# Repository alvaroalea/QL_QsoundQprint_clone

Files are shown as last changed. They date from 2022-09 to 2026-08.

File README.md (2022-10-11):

# SINCLAIR QL QsoundQprint Sound and Paralel Printer port interface

(C) 2022 Alvaro Alea Fernandez

License under: CERN Open Hardware Licence Version 2 - Strongly Reciprocal

https://ohwr.org/cern_ohl_s_v2.txt

I try to follow the original desing as much as possible, with some licenses:

- It's 10mm short, to fit in a 10x10cm, that is a lot cheaps if order PCB.
- The 7805 regulator board and the output Jack was modify.
- I use a electrolitic capacitor instead the original tantalo one.
- There are some jumper to allow a future ACB stereo mix.

This project can not be possible without the help of silvester, that tracked a fault in the schematic and Marcel Kilgus that develop a new ROM with a qsound device and a pt3 player.

I test with ROM versions 1.10, 1.31 and 1.40 and work as expected, new ROM do not have the printer routines, but have a new options used by the pt3 player. 

You can use a 2764 eprom or a W27C512 flash, that is much more cheap and easy to use.

This board user the default Motorola 68K inteface as described in the documentation of AY-3-8910 PSG. with a 6821 PIA as a glue between the QL and the PSG, in the info folder you can found aditional information about this chips or the interface.

The card have full 8bit I/O in the PSG without use, and another 8 bits in the PIA, also the pins of the paralel port are directly wired to the PSG, and are bidirectional, so can be used for other propouses.

The board use the E signal as a clock for the PSG, this cause that the PSG work in a very low frecuency, below the minimun indicated in the datasheet, and also this cause that tunes from Spectrum or other systems, can not be directly converted.

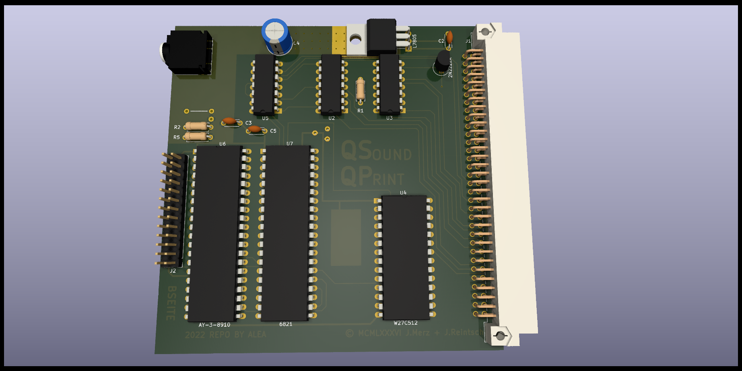
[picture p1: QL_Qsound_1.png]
 

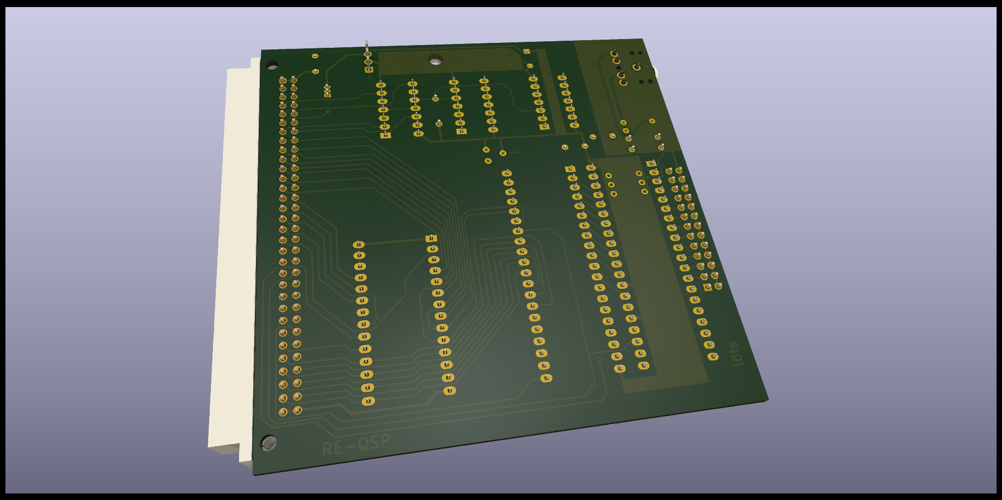
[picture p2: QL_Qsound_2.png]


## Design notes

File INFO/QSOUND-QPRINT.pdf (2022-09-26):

QSOUND/QPRIIdT - MANUAL | PAGE 1
This upgrade adds to the good characteristics | of the QL a 'real' sound generation facility and a parallel | printer

interface.
he boy
Ensure that the ",r is dis | . If you do

not you may damagr the QL, the QSOUND/QPRINT board or both. Remove the rectangular plastic cover on the left hand side of your QL which covers the expansion bus slot. This may require some effort.

Now push the QSOUNDIQPRINT board | firmly in the expansion
slot. | This may take also a little effort. You should be able
to feel when the board is firmly in place.

To test your new upgrade connect the QL to the mains. After
the usual memory test screen, the TV/Monitor selection screen will | appear with a11 additional copyright message | from the

QSOUND/QPRINT board. If you have connected an amplifier you should hear a short sound like a bell: QSOUND/QPRINT tells you that it is OK! After pressing F1 (or F2) you can use the full power of your QSOUND/QPRINT expansion.
To connect an amplifier to the QSOUND/QPRINT card, there is a 3.5 mm cinch socket on the left hand side of the card. | You
will also find a centronics compatible printer | interface
there,

Obligatory notice
QL, QDOS. Microdrive and SuoerBASIC are trade marks of ~inciair Research Ltd.
ABACUS, ARCHIVE, EASEL and QUILL are trade marks of Psion Ltd.

QSOUND/QPRINT - MANUAL | PAGE 2

lr_se
After powering up and initialisation | you can use a | new QL
device named PAR.
You can connect a Centronics | compatible printer | to | the
parallel interface and use it via the device name PAR.
A procedure to | list | the actual | SuperBASIC | program | to a
printer connected to the PAR port could look like this:

30000 DEFine PROCedure llist
30001 OPEN #3,PAR : LIST #3 : CLOSE #3 30002 END DEFine

### Bwffers

You can use a part of the QL's RAM as a buffer for efficient
print spooling. Its size In | blocks | of | 512 bytes must be
specified in the OPEN command as in the following examples:

OPEN #3, PAR-1
OPEN $3, PAR-32

512 byte buffer
16 kbyte buffer
The maximum buffer size is 63 kbytes.

Oations
Two options are accepted as part of the device name.
PARC-(bfsize) | The | 'C' flag | is used | if the | <LF> character
(chrS(10)) should be converted | to a | (CR>
character (chrS(13)).
PARF-<bfsize> | The 'F' flag is used | if a | IFF) | character
should be sent when the channel is closed. PARCF-(bfsize) Combination of the two flags is allowed.

SER em-Using the new PAR-USE command you can get the benefits of
your | new | parallel | interface | without changing existing
hrograms. | his command accepts a three character device name
!wrth or without string quotes) as a parameter.
PAR-USE SER | will | emulate the | SEX ports of the QL. All
output sent to the serial port will be send to the new PAR device.

Psion software
If you want | to use | the PAR | interface with ABACUS, ARCHIVE
EASEL and QUILL you may | include the PAR-USE - | command in the
corresponding boot prog;am.
Alternativly, you can also change the printer driver with the

QSOUND/QPRINT - MANUAL | PAGE 3

INSTALL-BAS program supplied with the Psion software package: Lead and run the program and choose the Microdrive as required. Choose the PAR port option by pressing the space bar. Get the list of printer parameters by pressing F2. Change the PORT by pressing either the left or right cursor key and then type 'PARf as the valid device name. Donft use a buffer unless you have a memory expansion as the

Psion programs use the entire RAM of an unexpanded QL.
Don't add the flags 'C' or 'Ft, You can obtain these options specifying the END OF LINE code as CR and by including FF in the POSTAMBLE CODE, respectively.

QSOUND/QPRINT - MANUAL | PAGE 4

The QSOUND/QPRINT firmware consists of 30 new SuperBASIC commands which allow you to utilize the PAR interface and the
full capability of | the | sound | chip. | A | few | useful
procedures/functions are also included.
The commands are described below. Parameters enclosed in < > are optional. The default window is #l.
BELL

CONTROL

CUR-FLASH f

CURDIS <#n>

CURSEN <#n>

procedure
causes the sound chip to emit a short bell like sound
procedure
creates a job which opens a window in the upper right-hand corner of the screen shows the number of the job that is currently ready to receive input (i.e. whose cursor is flashing)
procedure
changes the flashing rate of the cursor f = 0 | normal
f = 1 | medium
f = 2 | high

procedure
disables the cursor in window #n

procedure
enables the cursor in window #n
The INKEYS | command doesn't | show | a cursor. | The following | function also
returns the character corresponding to the key pressed but shpws a flashing cursor for the number of frames specified in m:

DEFine FUNction getkeyS(chn, wait) CURSEN #chn
rS=INKEYS(#chn, wait)
CURDIS #chn
RETurn rS
END DEFine
function
returns the current display mode m = 4 high resolution (4 c~lours) m = 8 low resolution (8 colours)

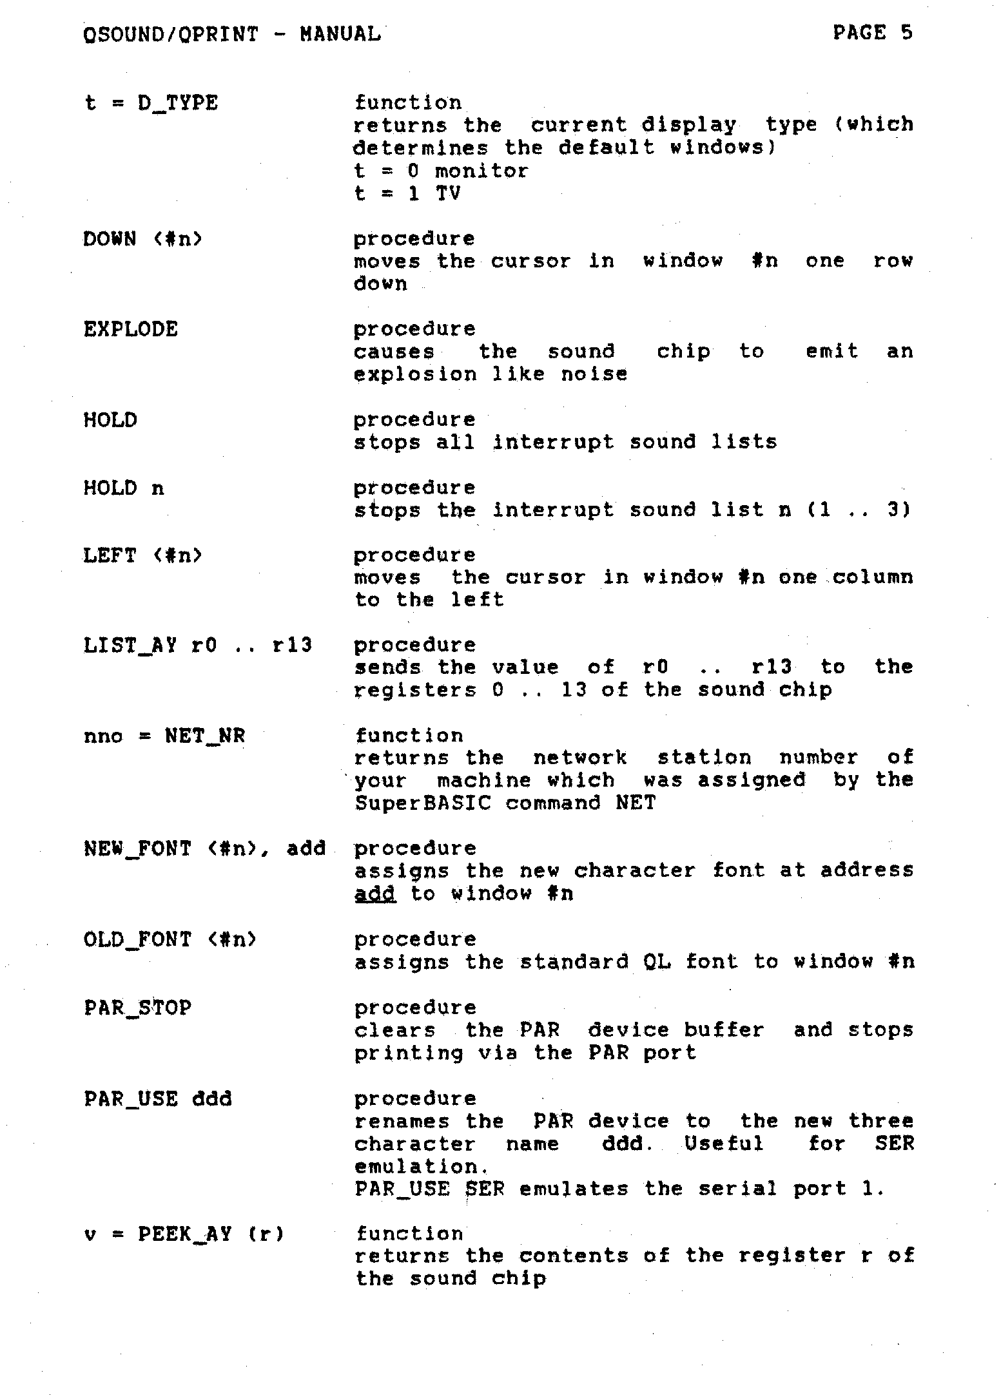
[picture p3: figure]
OSOUNDIQPRINT - MANUAL; PACE 5; DOWN <#n>; EXPLODE; HOLD; HOLD n; LEFT <In>; LIST-AY rO . .; nno = NET-NR; function returns the current display type (which determines the default windows) t = 0 monitor t=lTV; procedure; procedure stops all interrupt sound lists; to the left; sends the value of rO .. r13 to the registers 0 .. 13 of the sound chip; function returns the network station number of your machine which was assigned by the SuperBASIC command NET; NEW-FONT <#n>. add procedure; to window tn; OLD-FONT <#n>; PAR-STOP; clears the PAR device buffer and stops printing via the PAR port; PAR-USE ddd; renames the PRR device to the new three; character; name; ddd.; Useful; for SER; emulation. PAR-USE 6ER emulates the serial port 1.; v = PEEK-AY Ir ); function; the sound chip

moves the cursor in window Xn one row down

causes | the sound | chip to | emit an explosion like noise

ptocedur e stops the interrupt sound list n (1 .. 3)

moves the cursor in window In one column

assigns the new character font at address

assigns the standard QL font to window tn

returns the contents of the register r of

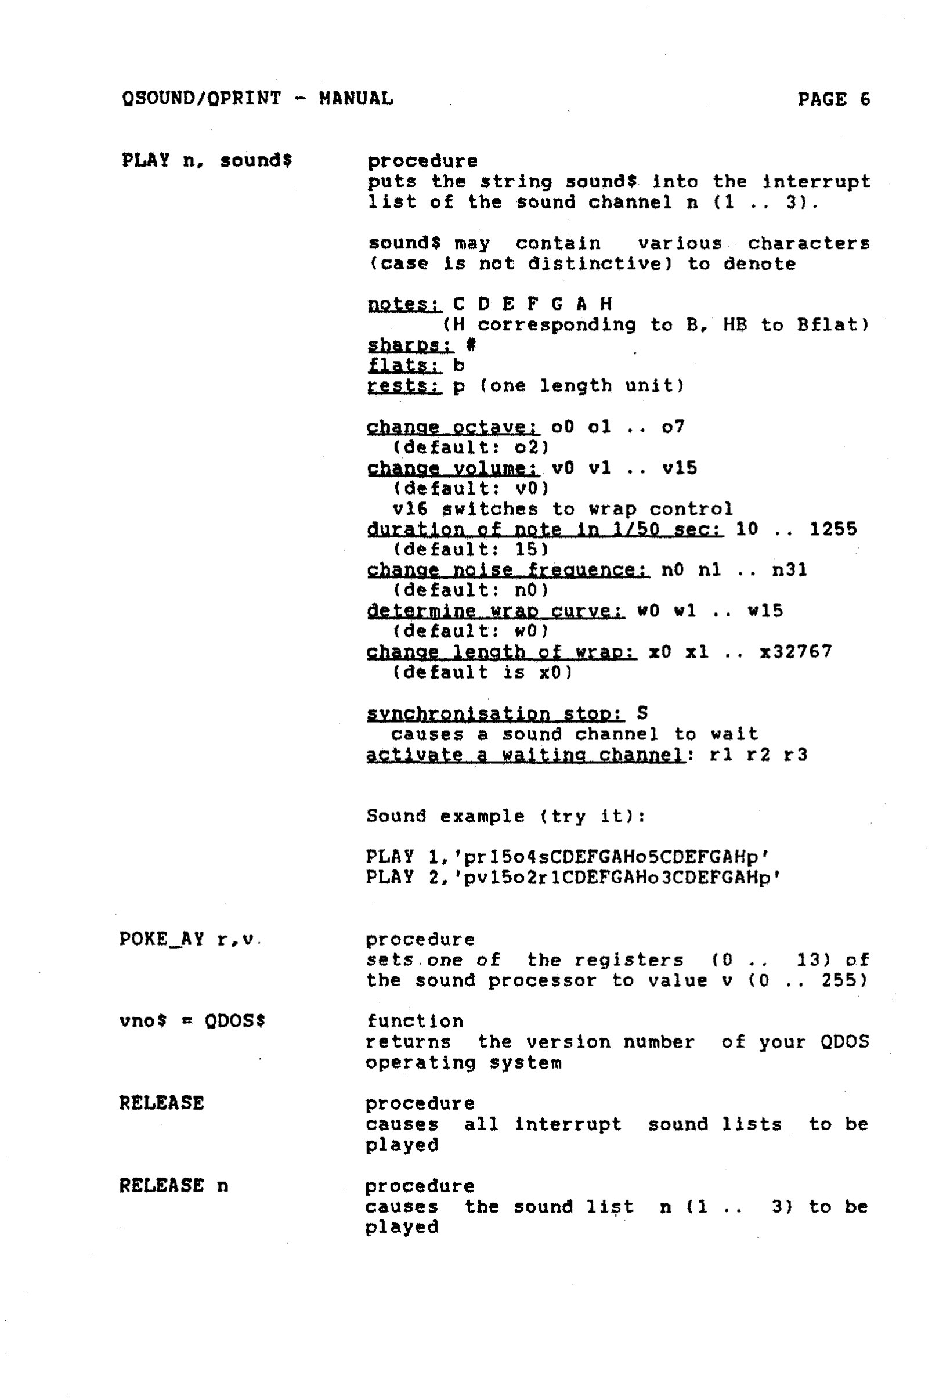
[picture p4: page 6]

QSOUND/QPRINT - MANUAL | PAGE 6
PLAY n, sound$ | procedure
puts the string sound$ into the interrupt list of the sound channel n (1 .. 3).

sound$ may contain various characters (case is not distinctive) to denote wtestC D E F G A H
(H corresponding to B, HB to Bflat) sharas:t
flars:b
rests: p (one length unit)
aanae octave: 00 01 .. 07

(default: 021

chansc v0 vl . . v15

(default: vO)
v16 switches to wrap control
of no* in 1150 sec: 10 ., 1255 (default: 15) * noise freouence: no nl . . n31

(default: no)
wraci curve& uO wl .. w15
(default: wO) oe lenath of wrao: x0 xl .. x32767

(default is xO)

sation stov: S causes a sound channel to wait

activate a waitina chaw: rl r2 r3

SounB example (try it):

PLAY l,'pr1504sCDEFGAHo5CDEFGAHpr PLAY 2,'pv1502r1CDEFGAH03CDEFGAHp'

POKE-AY r,v.

vnoS QDOSS

RELEASE

RELEASE n

procedure
sets one of the registers 10 .. 13) of the sound processor to value v (0 . . 255)

function
returns the version number of your QDOS operating system

procedure
causes all interrupt sound lists to be played

procedure
causes the sound list n (1 .. 3) to be played

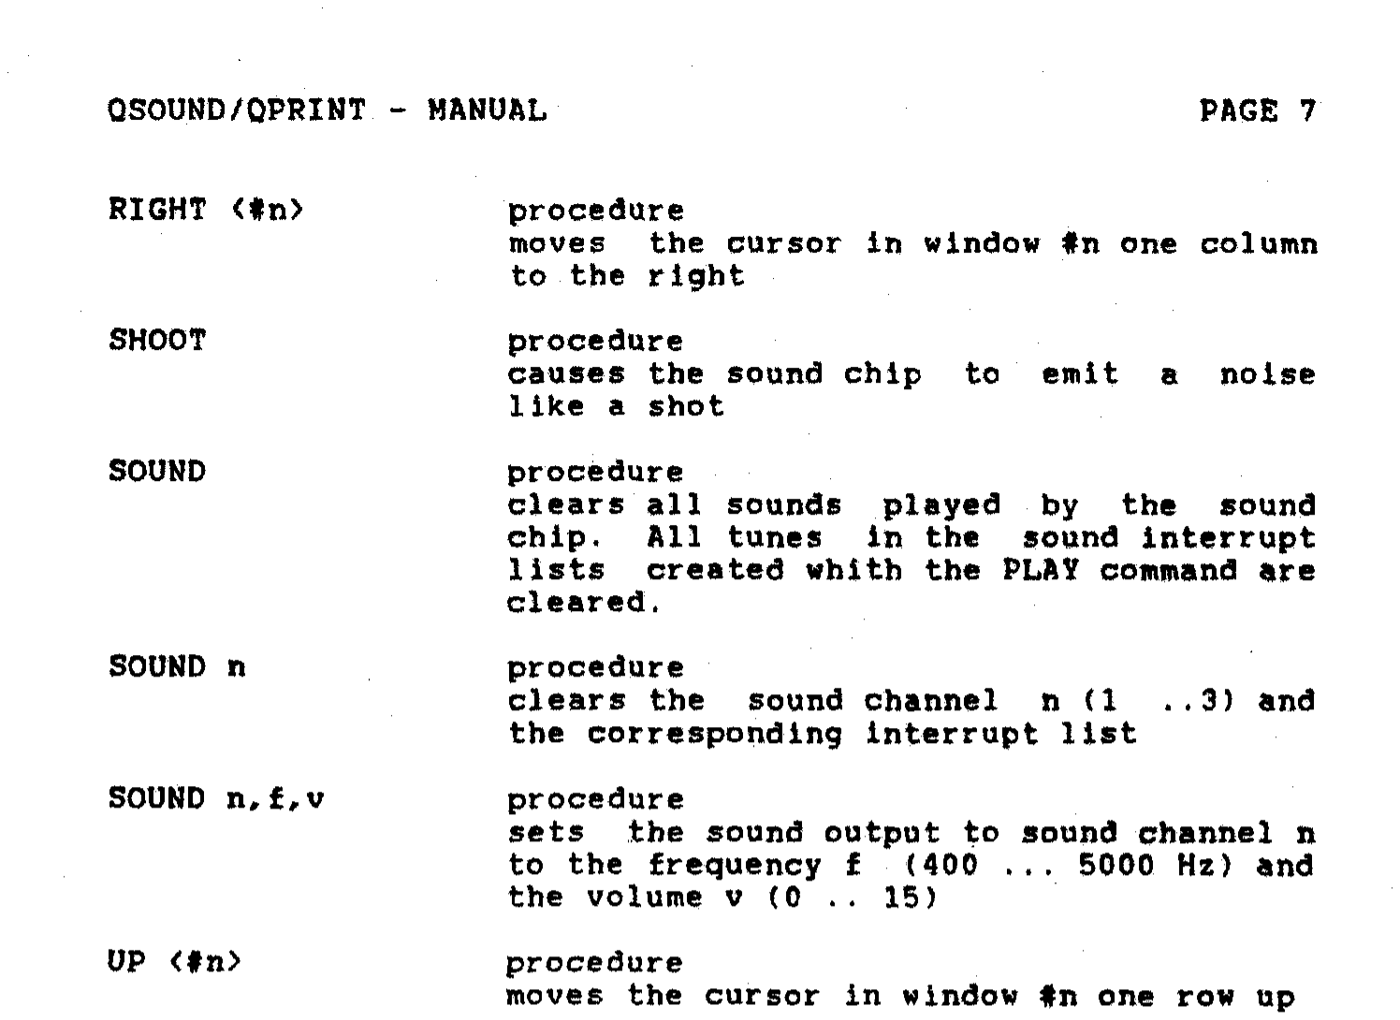
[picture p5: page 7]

QSOUND/QPRINT - MANUAL | PAGE 7
RIGHT <en> | procedure
moves the cursor in window In one column to the right
SHOOT

SOUND

SOUND n

SOUND n, f,v

procedure
causes the sound chip to emit a noise like a shot
procedure
clears all sounds played by the sound ship. All tunes in the sound interrupt lists created whith the PLAY command are cleared.

procedure
clears the sound channel n (1 ..3) and the corresponding interrupt list procedure
sets the sound output to sound channel n to the frequency f (400 ... 5000 Hz) and the volume v (0 .. 15)

procedure
moves the cursor in window #n one row up

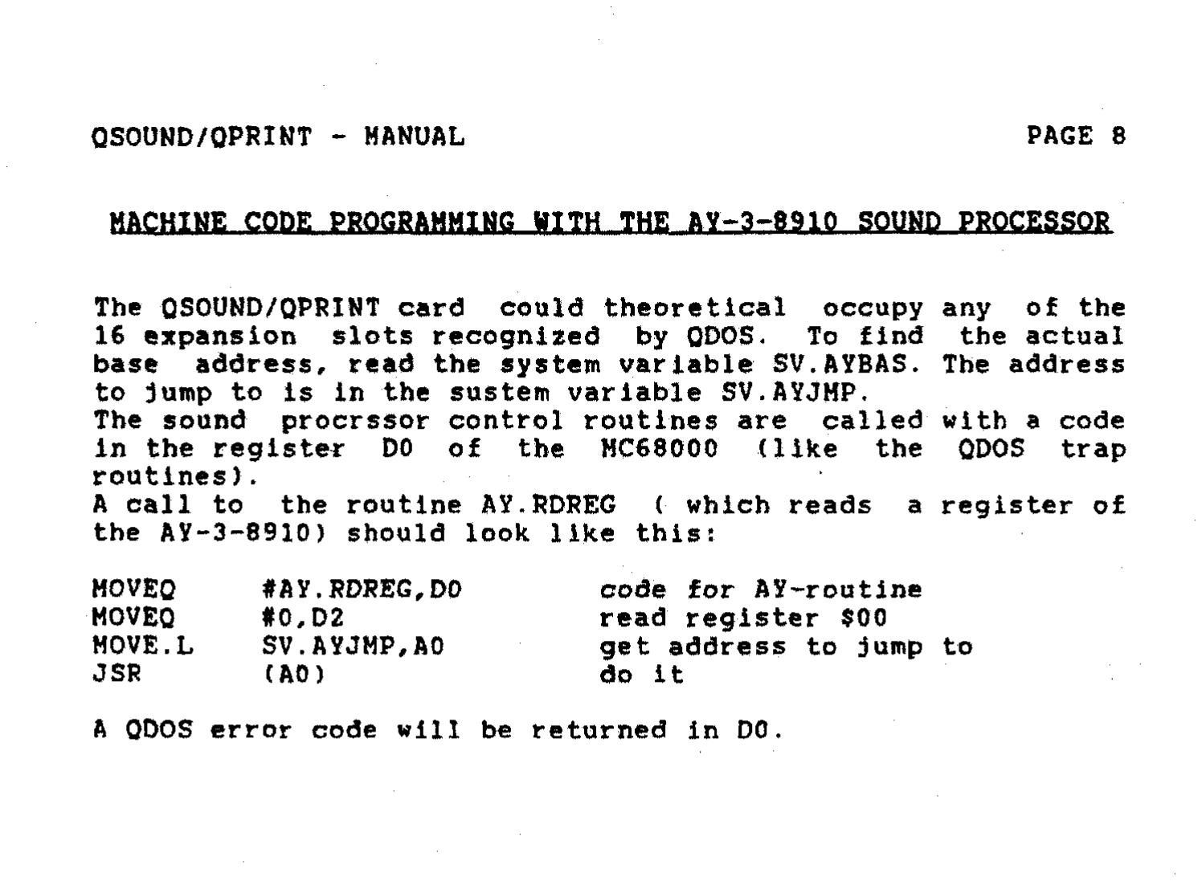
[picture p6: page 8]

QSOUNDlOPRINT - MANUAL | PAGE 8

SOUND PROC=

The QSOUND/QPRINT card could theoretical occupy any of the

### 16 expansion slots recognized by 0005. To find the actual

base address, read the system variable SV.AYBAS. The address to jump to is in the sustem variable SV.AYJNP.
The sound procrssor control routines are called with a code In the register DO of the MC68000 (like the ODOS trap routinesl.
A call to the routine AY.RDREG ( which reads a register of the AY-3-8910) should look like this:
HOVEQ | #AY. RDREG, DO | code for AY-routine
HOVE0 | 20, D2 | read register SO0
H0VE.L | SV.AYJMP,AO | get address to jump to
J SR | (AD) | do it

A QDOS error code will be returned in DO

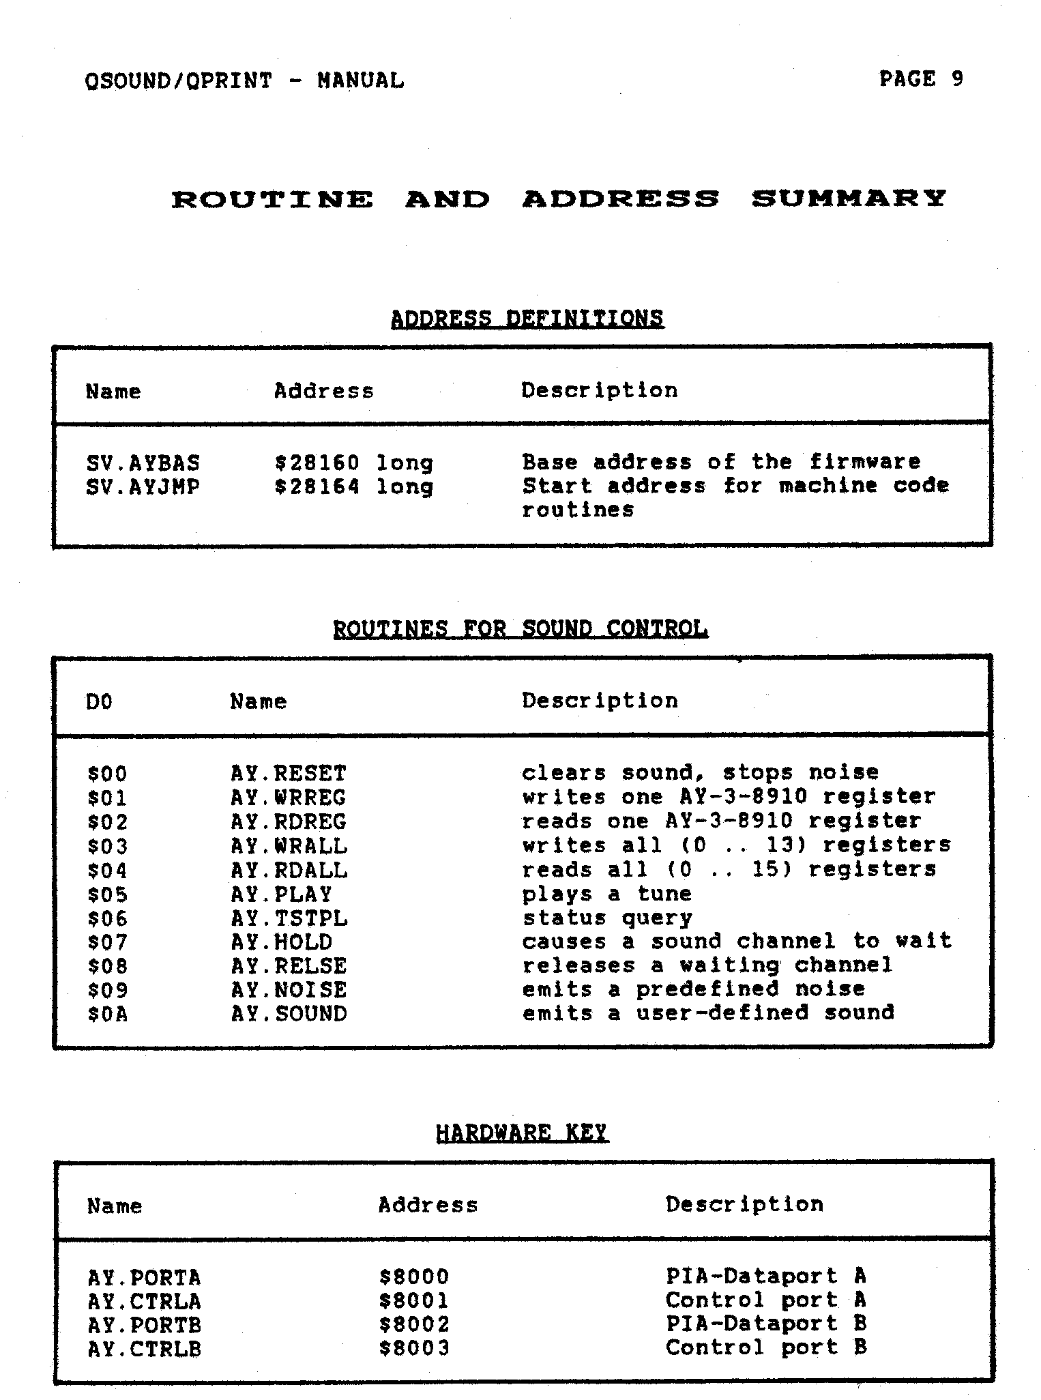
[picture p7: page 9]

QSOUND/PPRINT - MANUAL | PACE 9

ROUTINE AND ADDRESS SUMMARY

Name | Address | Description
SV. AYBAS | $28160 long | Base address of the firmware
SV.AYJMP | $28164 long | Start address for machine code
| | routines
FOR SOUND C | m
I
Name | Description

AY. RESET
AY. WRREG
AY . RDREG
AY. WRALL
AY. RDALL
AY. PLAY
AY. TSTPL
AY .HOLD
AY. RELSE
AY .IOISE
AY. SOUND

clears sound, stops noise
writes one AY-3-8910 register reads one AY-3-8910 register writes all (0 .. 13) registers reads a11 (0 .. 15) registers plays a tune
status query
causes a sound channel to walt releases a waiting channel emits a predefined noise
emits a user-defined sound
I Name | Address | Description | I
I AY. PORTA | $8000
AY, CTRLA | $800 1
AY, PORTB | $8002
AY. CTRLB | $8003 | PIA-Dataport A
| | Control port A PIA-Dataport B
| | Control port B

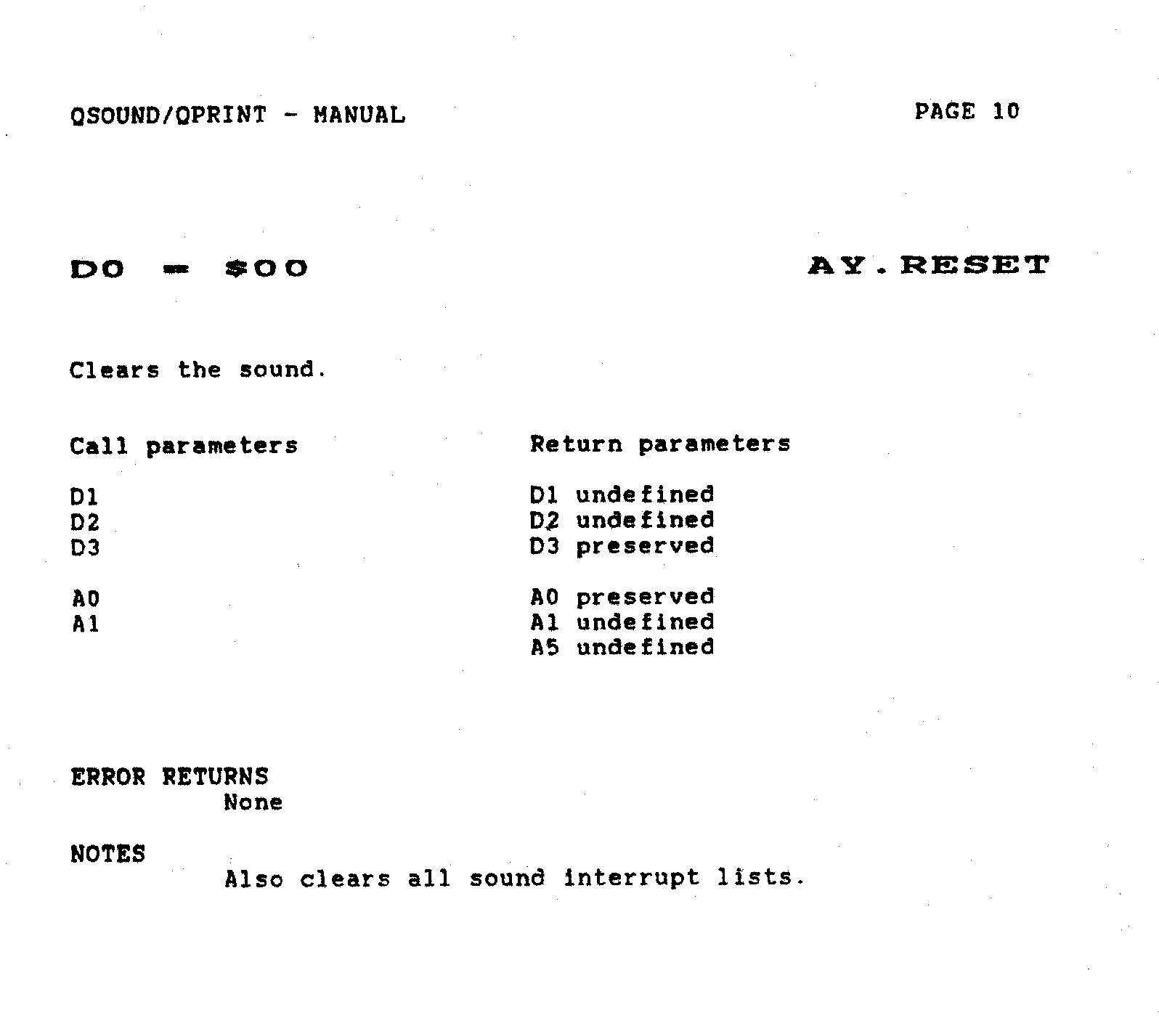
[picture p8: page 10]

QSOUND/QPRINT - MANUAL

Clears the sound.

Call parameters

ERROR RETURNS
None

Return parameters
Dl undefined
D2 undefined

### 03 preserved

A0 preserved
A1 undefined
A5 undefined

PAGE 10

AY, RESET

NOTES
Also clears all sound Interrupt lists.

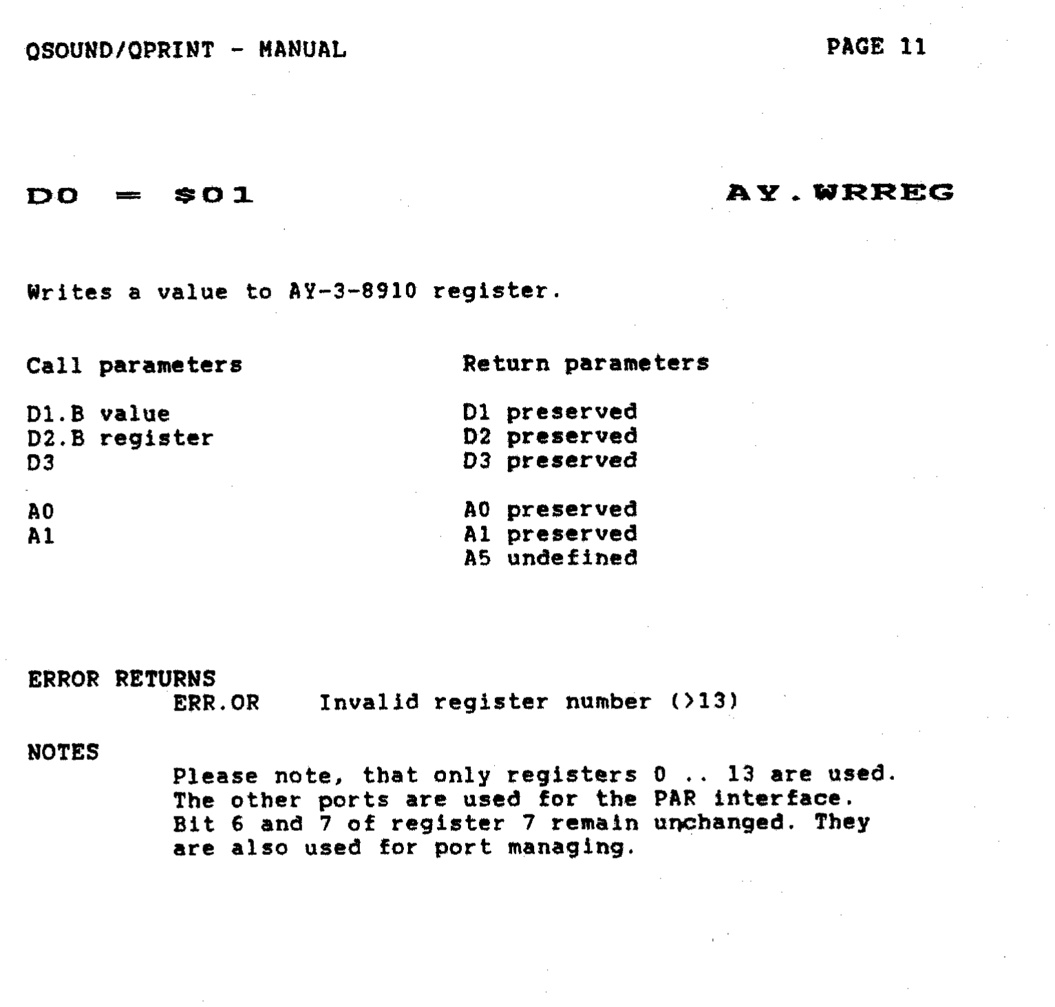
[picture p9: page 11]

QSOUND/PPRINT - MANUAL

Writes a value to AY-3-8910 | register.
Call parameters | Return parameters

AY, WRREG

D1.B value
D2.B register
D 3

Dl preserved
D2 preserved
D3 preserved
A0 preserved
A1 preserved
A5 undefined

PAGE 11

ERROR RETURNS
ERR.OR Invalid register number 013)
NOTES
Please note, that only registers 0 . . 13 are used. The other ports are used Zor the PAR interface. Bit 6 and 7 of register 7 remain unchanged. They are also used for port managing.

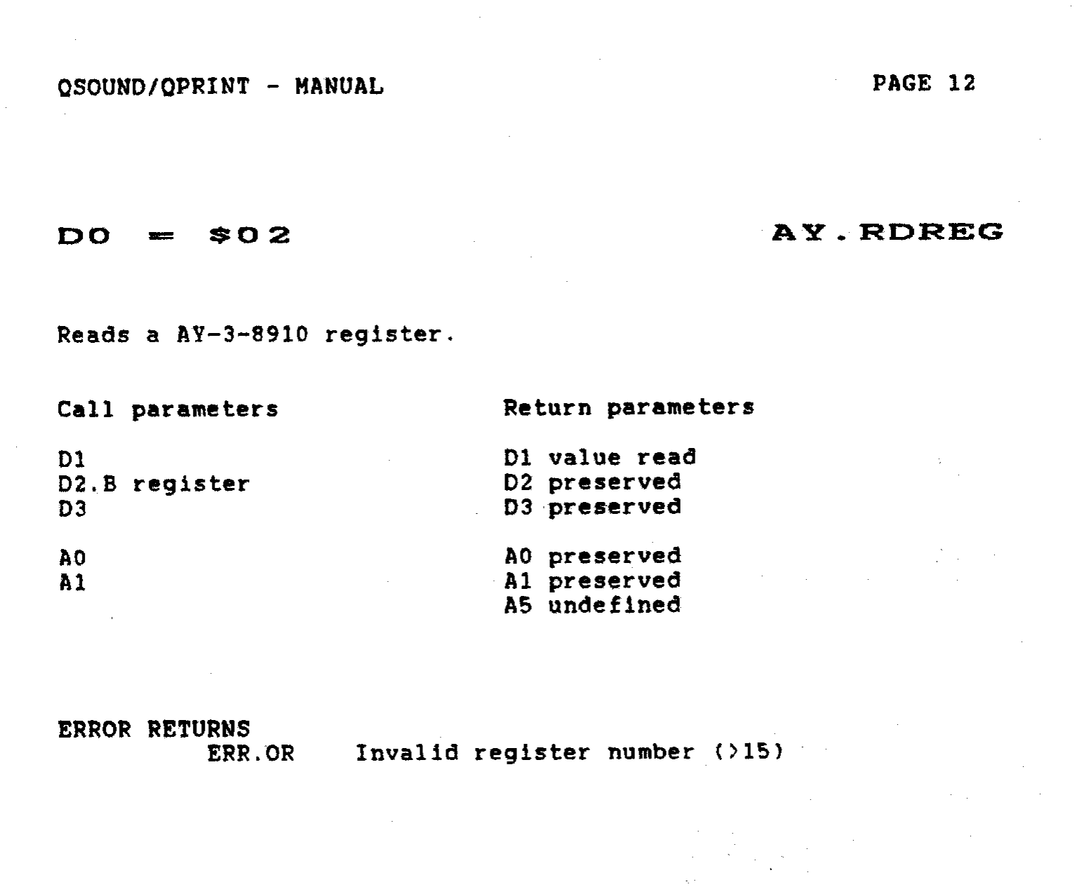
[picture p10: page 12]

QSOUND/QPRINT - MANUAL

Reads a AY-3-8910 register.

Call parameters

D 1
D2.B register
D 3

Return parameters
Dl value read
D2 preserve6
D3 preserved
A0 preserved
A1 preserved
A5 undefined

PAGE 12

AY. RDREG

ERROR RETURNS
ERR.OR Invalid register number 015)

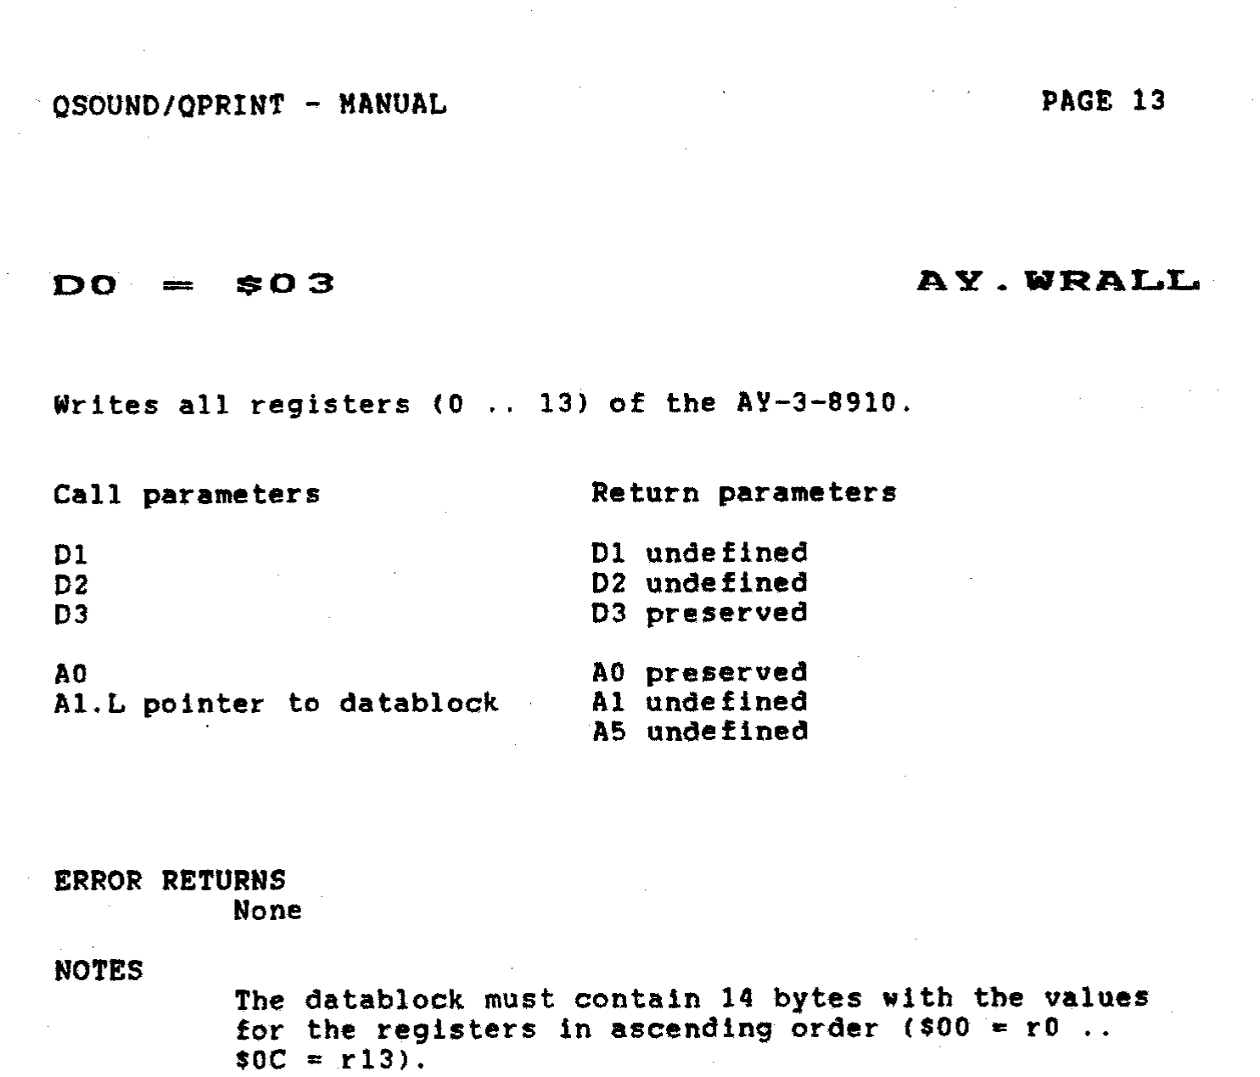
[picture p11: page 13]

QSOUND/QPRINT - MANUAL | PAGE 13
DO | = SO 3 | AY. WRALL

Writes all registers (0 .. 13) of the AY-3-8910.

Call parameters | Return parameters
Dl undef incd
D2 undefined
D3 preserved
A0 | A0 preserved
A1. L pointer to datablock | A1 undefined
A5 undcf ined

ERROR RETURNS
None

NOTES
The datablock must contain 14 bytes with the values for the registers In ascending order ($00 = rO .. SOC = r13).

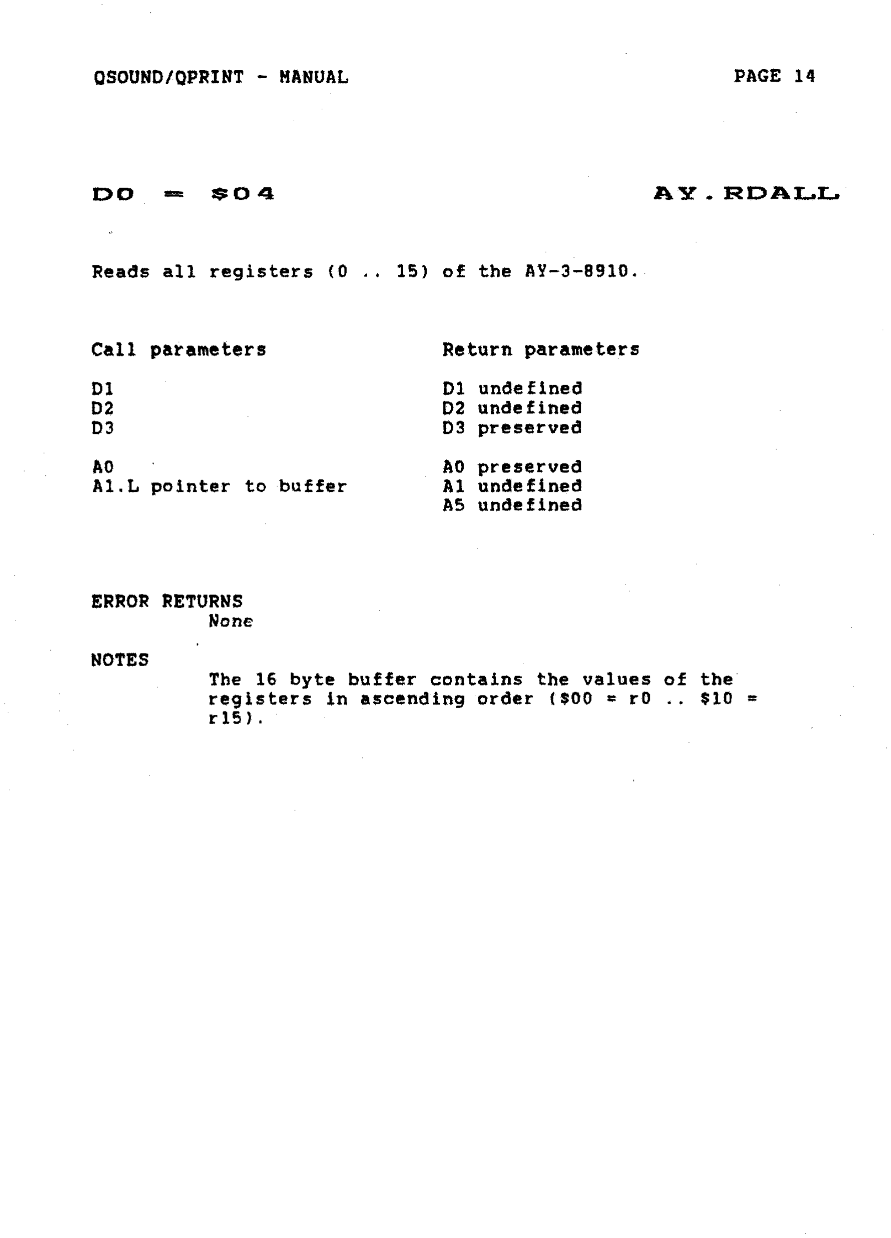
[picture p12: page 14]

OSOUND/QPRINT - MANUAL | PAGE 14

AY, RDALL

Reads all registers (0 .. 15) of the AY-3-8910.

Call parameters | Return parameters
| Dl undefined
| D2 undefined
| D3 preserved
A0 | A0 preserved
A1 .L pointer to buf fcr | A1 undefined
| A5 undefined

ERROR RETURNS
None

NOTES
The 16 byte buffer contains the values of the register; in ascending order 1$00 = rO . . $10 = t-15).

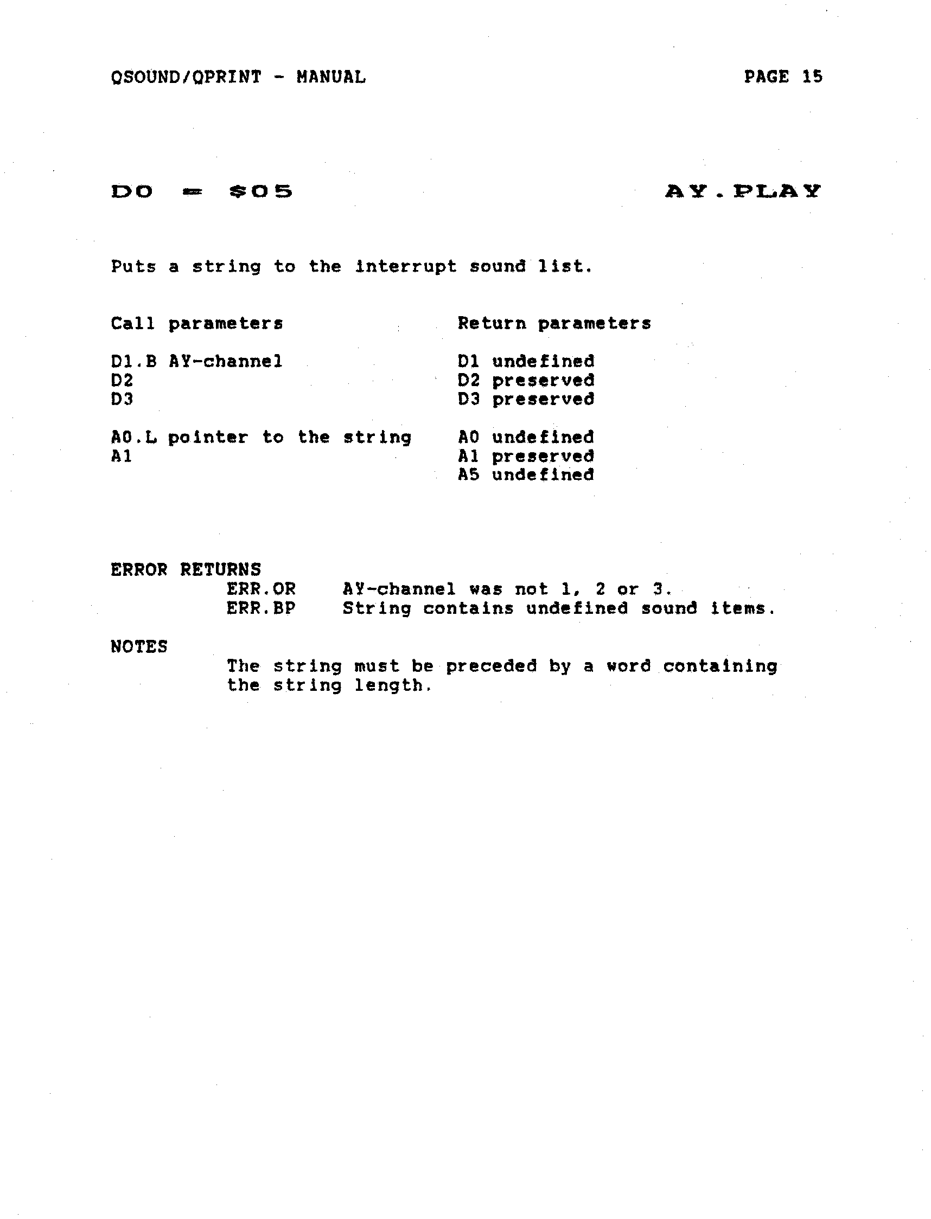
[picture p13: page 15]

QSOUND/QPRINT - MANUAL | PAGE 15

AY - PLAY

Puts a string to the interrupt sound list.

Call parameters | Return parameters
D1.B AY-channel | Dl undefined
D 2 | D2 preserved
D3 | D3 preserved
A0.L pointer to the string | A0 undefined
A1 | A1 preserved
| A5 undefined

ERROR RETURNS
ERR.OR | AY-channel was not 1, 2 or 3.
ERR.BP | String contains undefined sound items.
NOTES
The string must be preceded by a word containing the string length.

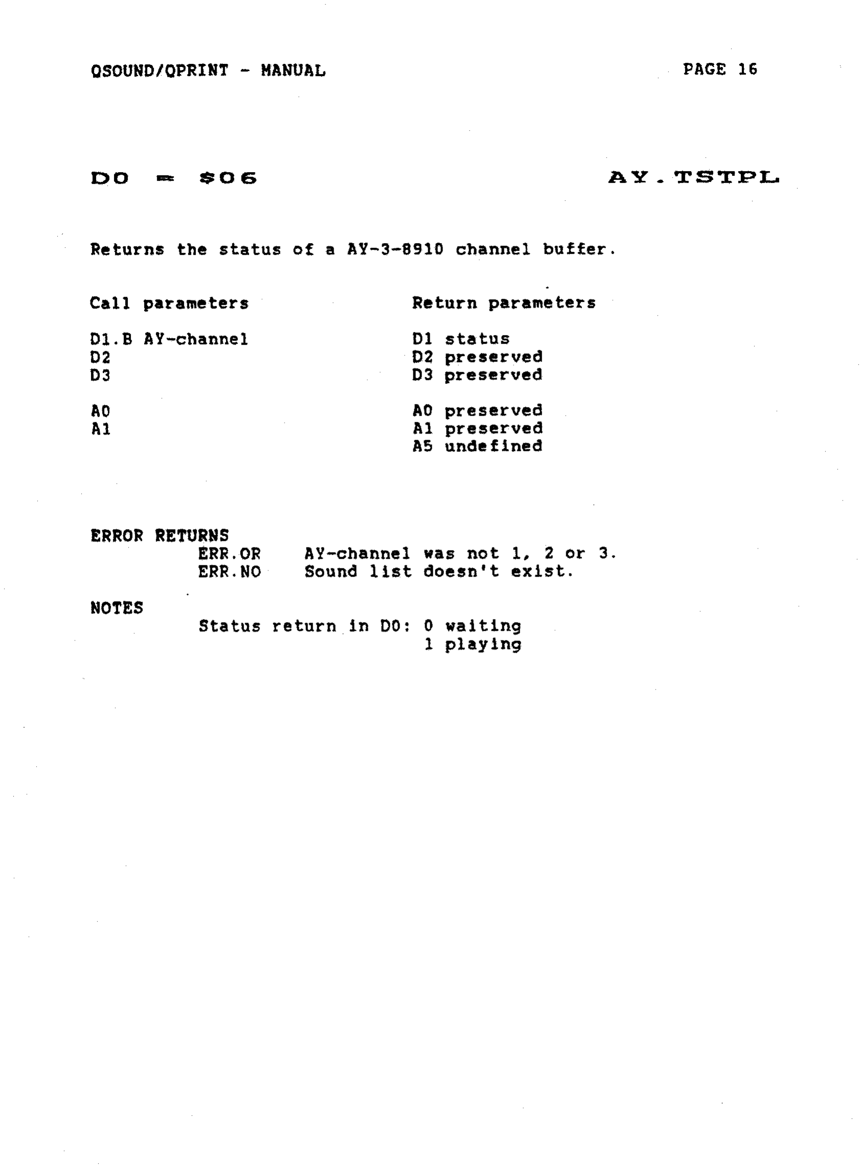
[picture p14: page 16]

QSOUND/OPRINT - MANUAL

Returns the status of a AY-3-8910 channel buffer.

AY | TSTPL
Call parameters | Return parameters
| Dl status D2 preserved D3 preserved
| A0 preserved A1 preserved A5 undefined

PAGE 16

ERROR RETURNS
ERR.OR | AY-channel wasnot 1, 2or 3.
ERR.NO | Sound list doesn't exist.

NOTES
Status return in DO: 0 waiting
| 1 playing

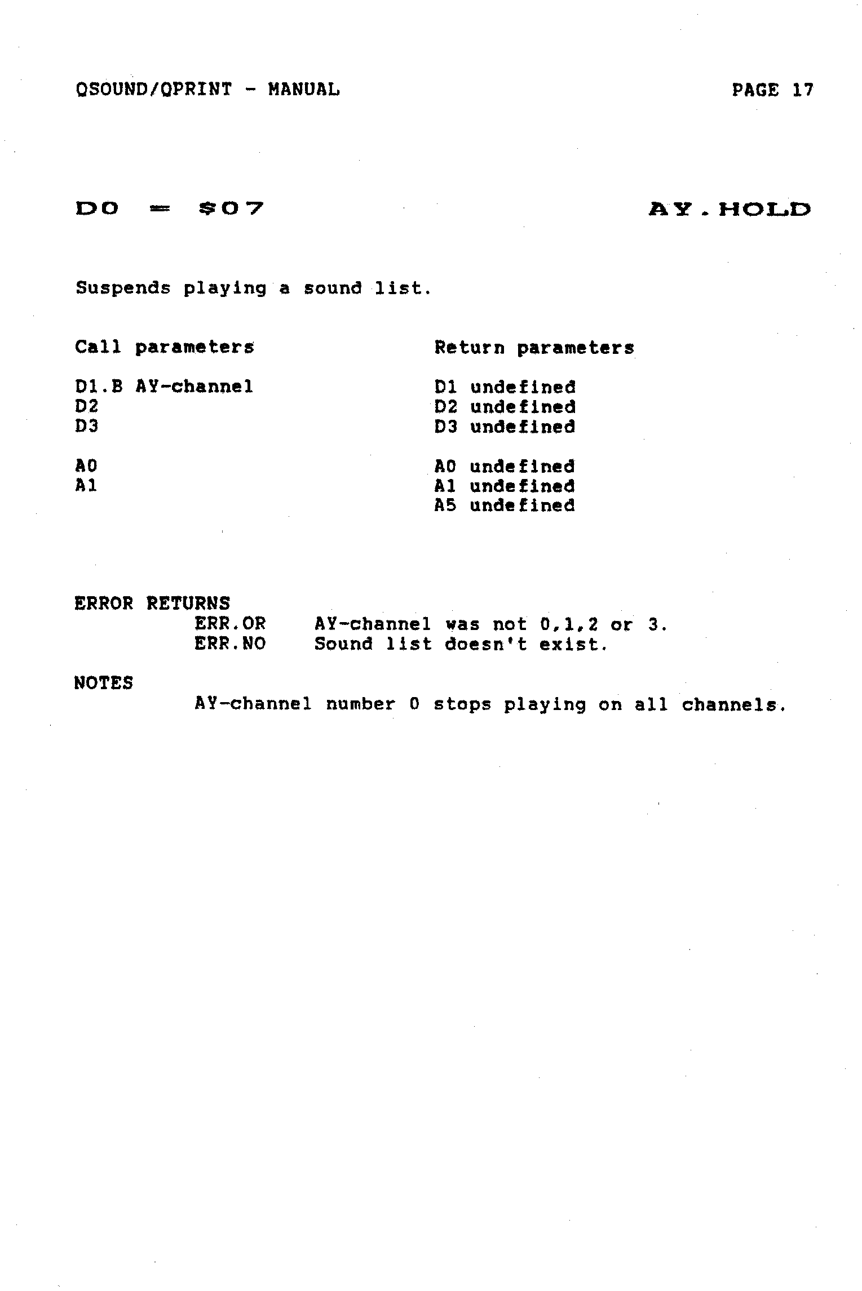
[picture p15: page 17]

QSOUND/QPRINT - MANUAL

Suspends playing a sound list.

Call parameters | Return parameters Dl undefined D2 undefined 03 undefined A0 undefined A1 undefined A5 undefined

PAGE 17

ERROR RETURNS
ERR.OR | AY-channel was not 0,1,2 or 3.
ERR.NO | Sound list doesn't exist.

AY. HOLD

NOTES
AY-channel number 0 stops playing on a11 channels.

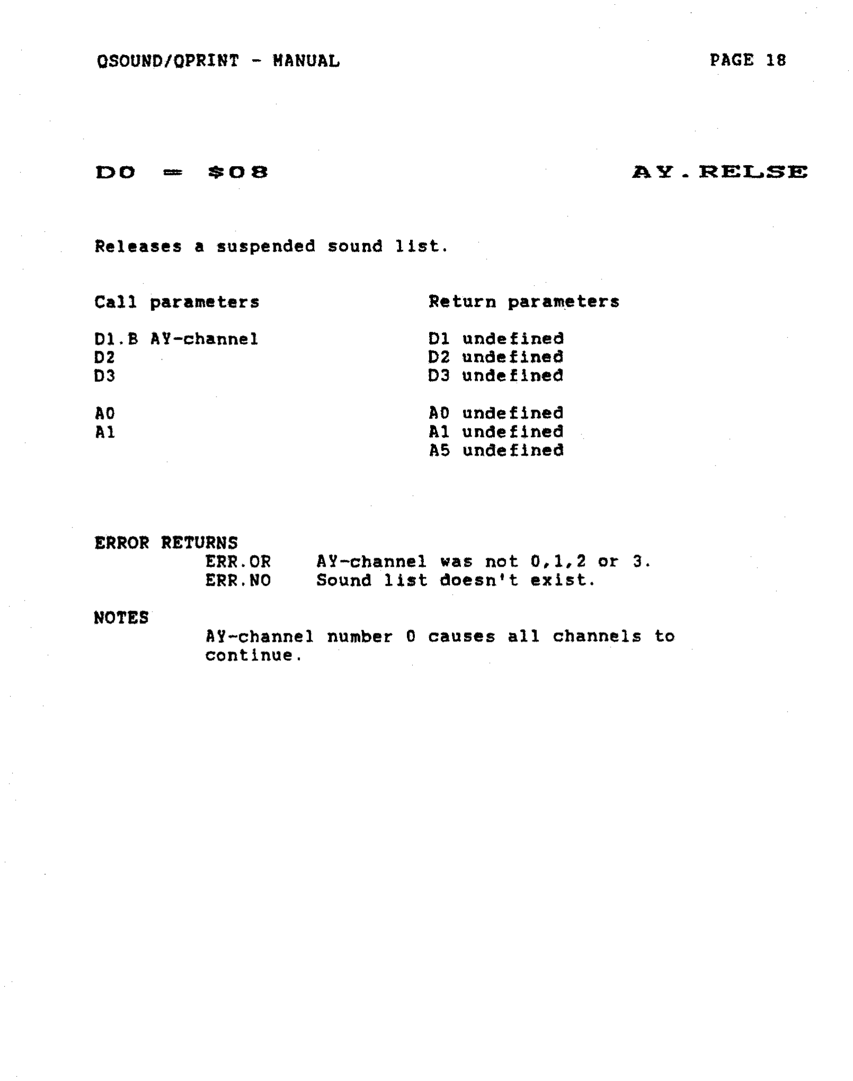
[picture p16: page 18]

Releases a suspended sound list.

Call parameters | Return parameters
| Dl undefined D2 undefined D3 undefined
| A0 undefined A1 undefined A5 undefined

PAGE 18

ERROR RETURNS
ERR.OR | AY-channel was not 0,1,2 or 3
ERR.NO | Sound list doesn't exist.

NOTES
AY-channel number 0 causes all channels to continue.

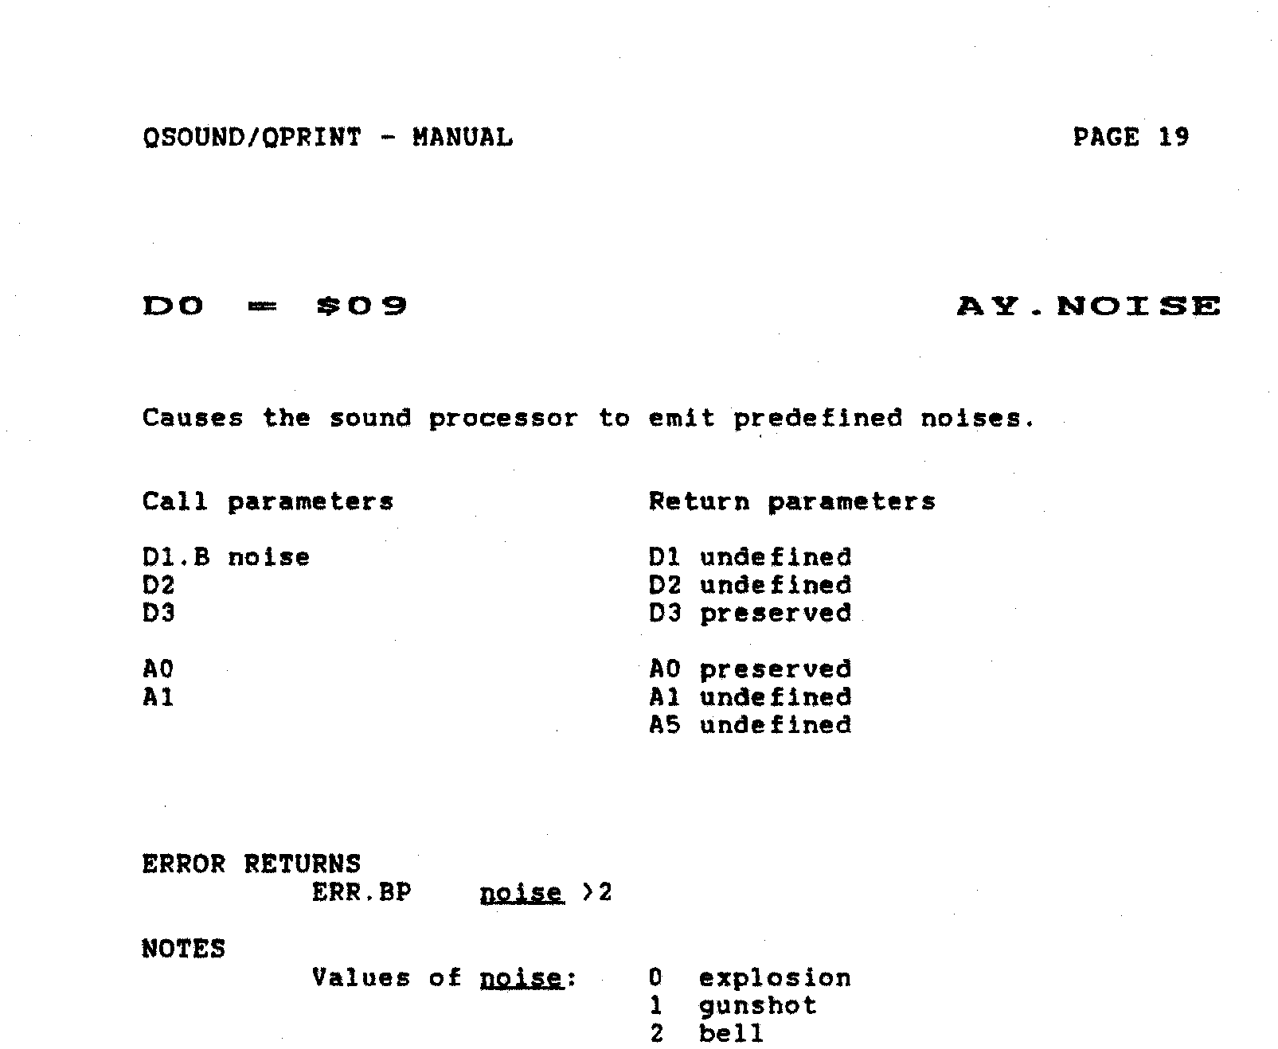
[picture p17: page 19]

QSOUND/QPRINT - HANUAL

AY. NOISE

Causes the sound processor to emit predefined noises

Call parameters | Return parameters
D1.B noise
D2
D3

ERROR RETURNS
ERR.BP aQige>Z

Dl undefined
D2 undef ined
D3 preserved
A0 preserved
A1 undefined
A5 undefined

PAGE 19

NOTES
Values of apLse: 0 explosion 1 gunshot 2 bell

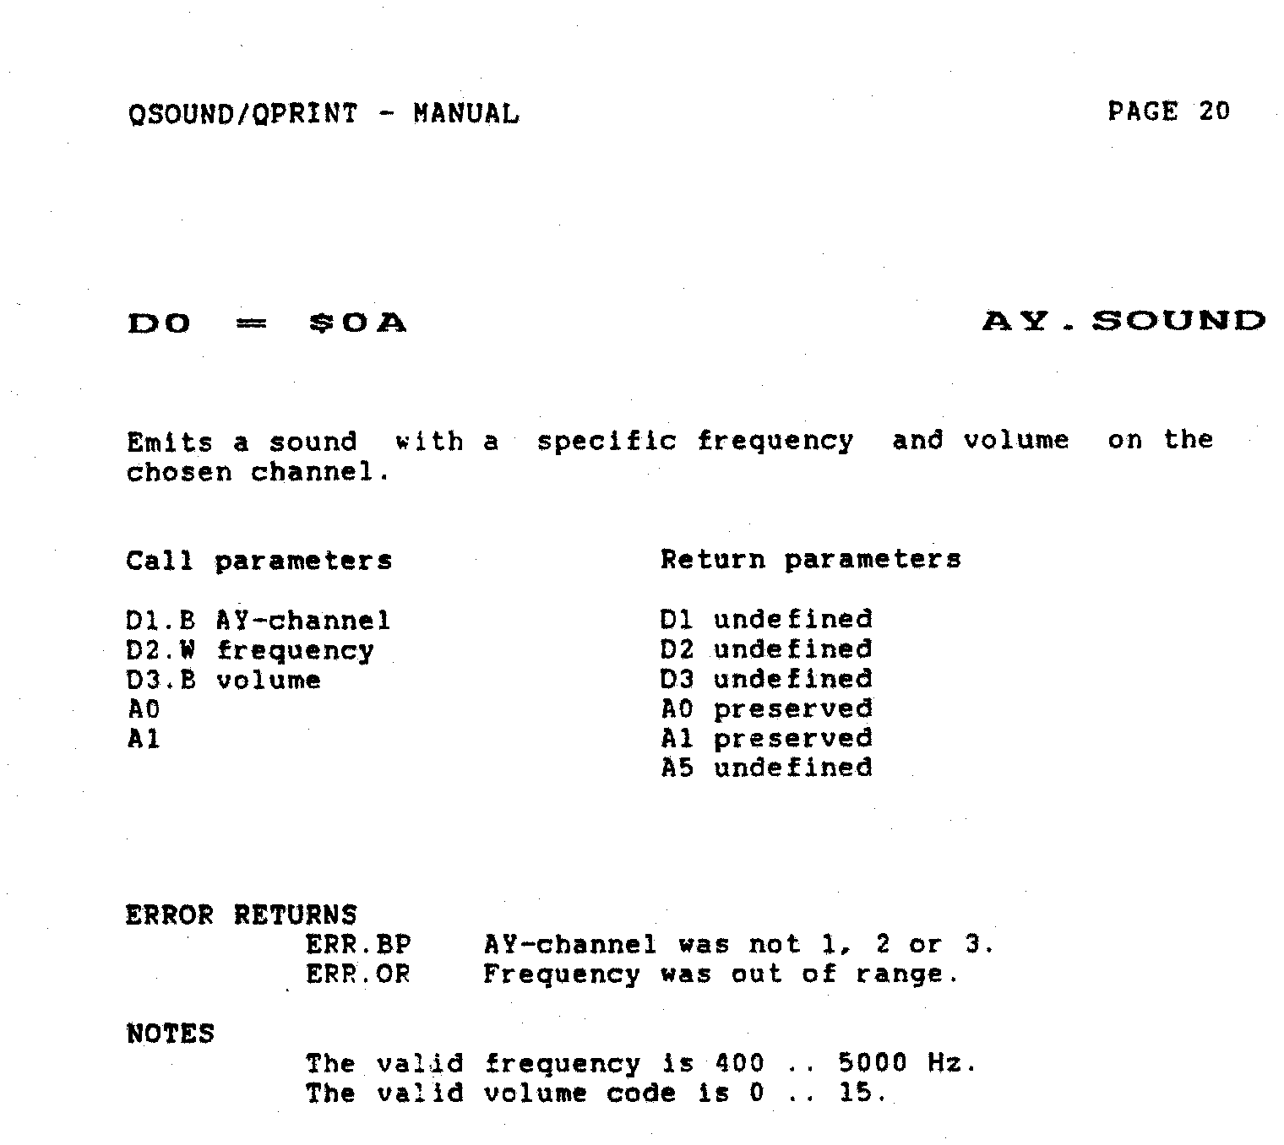
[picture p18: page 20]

OSOUNDlQPRfNT - MANUAL | PAGE 20

AY. SOUND

Emlts a sound with a specific frequency and volume on the chosen channel.

Call parameters | Return parameters
Dl. B AY-channel
02. W frequency
D3.B volume A0 A 1 | Dl undefined D2 undefined 03 undefined A0 preserved A1 preserved A5 undefined

ERROR RETURNS
ERR.BP | AY-channel was not 1. 2 or 3.
ERR.OR | Frequency was out of range.
NOTES
The valid frequency is 400 .. 5000 Hz The valid volume code is 0 .. 15.

QSOUND/QPRINT - MANUAL | PAGE 21

The sound processor AY-3-8910 works with a 0.75 MHz time frequency on the OL. It uses 16 read/write registers. The use of the registers is described below.

I re9 | bit | 7 | 6 | 5 | 4 | 3 | 2 | 1 | 0
SO0 chn A tone | LSB | 7 | 6 | 5 | 4 | 3 | 2 | 1 | 0
$01 chn A | MSB | x | x | x | x | B | A | 9 | B
$02 chn B tone | LSB | 7 | 6 | 5 | 4 | 3 | 2 | 1 | 0
$03 chn B | M SB | x | x | x | x | B | A | 9 | 8
$04 chn C tone | LSB | 7 | 6 | 5 | 4 | 3 | 2 | 1 | 0
$05 chn C | MSB | x | x | x | x | B | A | 9 | 8
$06 noise period | | x | x | x | x | 3 | 2 | 1 | 0
007 release | ioB ioA nC nB nA sC sB sA
$08 chn A amplitude | x | x | x | w | 3 | 2 | 1 | 0
$09 chn B amplitude | x | x | x | w | 3 | 2 | 1 | 0
SOA chn C amplitude | x | x | x | w | 3 | 2 | 1 | 0
SOB wrap period | LSB | 7 | 6 | 5 | 4 | 3 | 2 | 1 | 0
$OC wrap period | MSB | F | E | D | C | B | A | 9 | 8
$OD wrap curve | x | x | x | x | w3 WZ wl w0
SOE 1/0 port A | | 7 | 6 | 5 | 4 | 3 | 2 | 1 | 0
$OF 1/0 port B | | 7 | 6 | 5 | 4 | 3 | 2 | 1 | 0

x: bit not used
ioh: If bit is set then port A is input channel else it is output channel.
ioB: If bit is set then port B is input channel else it is output channel.
nA .. nC: If bit is reset channel is emitting noise.
sA .. sC: If bit is reset channel is emitting sound.
YO .. w3: Wrap curve (cf. page 22) w: Bit activates wrap control.

wters $00 . . $05 define the pitch of the channel. Two registers define a note. The main time is divided by 16. By counting down the 12-bit-counter the output frequency is generated.
tar $06 defines the noise frequency. This works like the pitch control but with 5 bits only.
&&s$ar $0.2 releases the sources. It selects pilrnca, sound, Q~iiEg or sound noie for each channel.

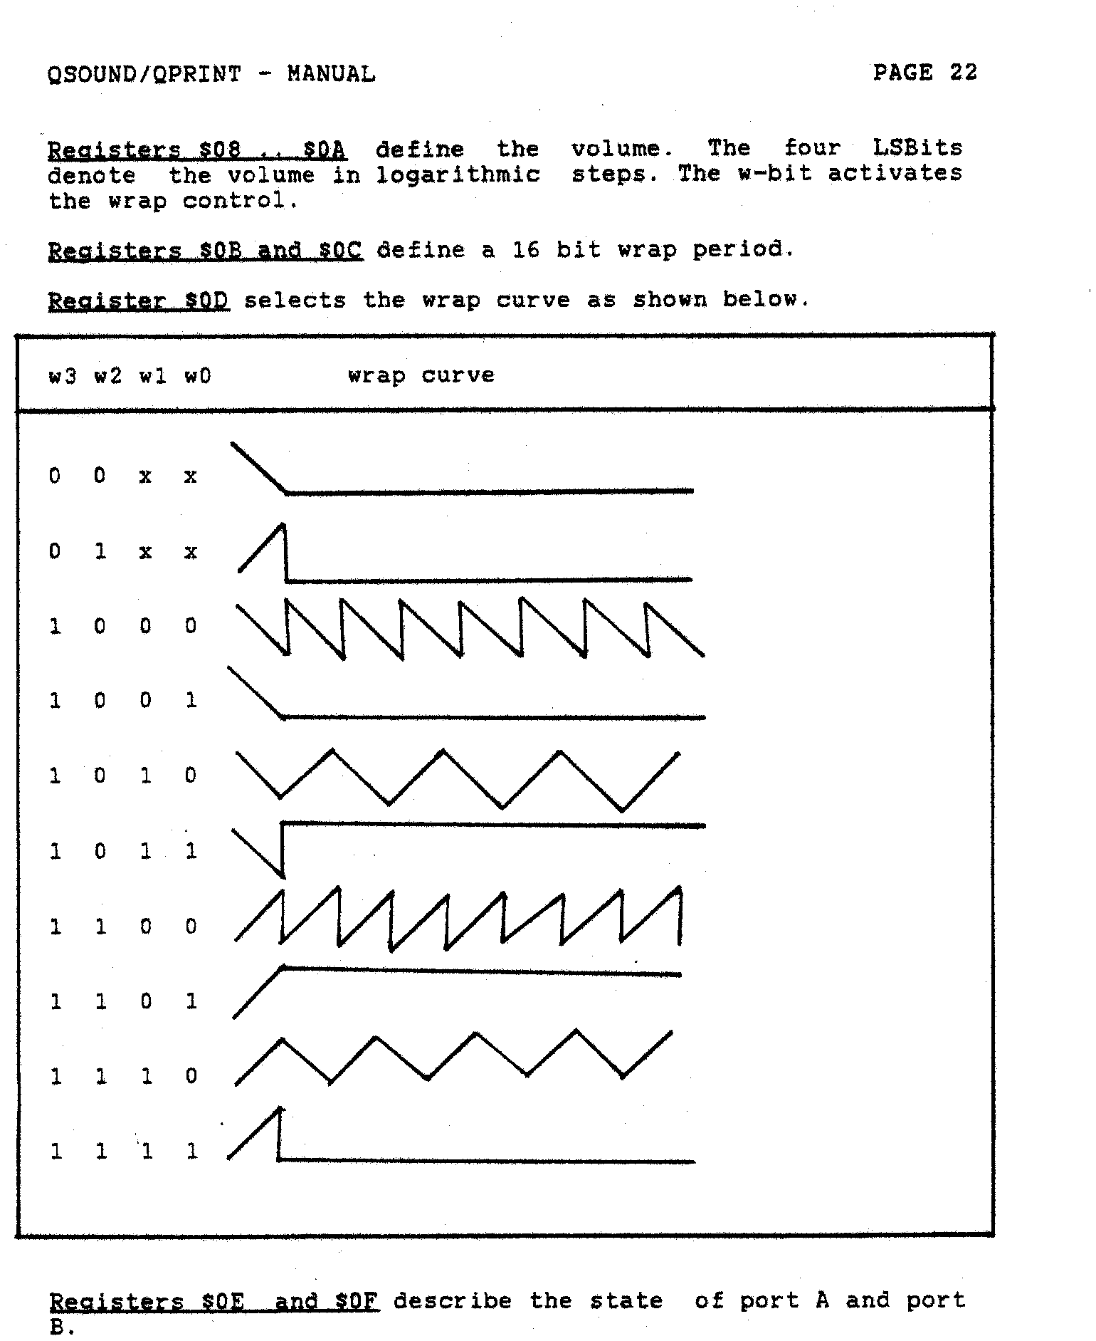
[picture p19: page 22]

QSOUND/QPRINT - MANUAL | PAGE 22
-rs | PO8 . . SO& define the volume. | The four LSBits

denote the volume in logarithmic steps. The w-bit activates the wrap control.
Rkcristers and $OQ Befine a 16 bit wrap period.

stet SOD selects the wrap curve as shown below.

w3 w2 wl w0 | wrap curve
ters POE and | describe the state of port A and port
B.

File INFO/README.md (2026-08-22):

# SINCLAIR QL QsoundQprint Sound and Paralel Printer port interface
(C) 2022 Alvaro Alea Fernandez

License under: CERN Open Hardware Licence Version 2 - Strongly Reciprocal

https://ohwr.org/cern_ohl_s_v2.txt

## Aditional info

Pictures of the original interfaz by Ioannis: https://qlforum.co.uk/viewtopic.php?f=2&t=1587&start=10#p17687

Interface Manual, from Dilwyn Jones site: http://www.dilwyn.me.uk/docs/manuals/index.html

6821 Manual, from archive.org

AY-3-8910 Manual, Silvester point to the source: https://dev-docs.atariforge.org/ , he also do the original schematic

## Technical Info

## Memory Map
The Sinclair QL expect that all external board use the last 256Kb of the 1Mb memory space (that is A19,A18=1)

The 'Plug-n-play' characteristic allow up to 16 "block" of 16Kb of memory can be shared between diferent expansion board, through the use of a
expecial SP0 to SP3 lines present in the expansion port.

This lines are tied to GND in the Sinclair QL Main Board, and compared with the actual A14 to A17 of the 68008, in real life, this mean, that if 
you are not using any expecial backplane to allow several card, or using a custom card that has passthrough conector, 
the Qsound memory base address will be on 0b110000xxxxxxxxxxxxxx or 0xC0000.

This is also the unique address that is recognized by some ROM versions.

Of this memory the first 8K (0xC0000 to 0xC1FFF) is decoded for the ROM of the Qsound.

The 6821 PIO is decoded using A0,A1 and A13 to A19, so will be available in the top 8K of the card (0b1100001xxxxxxxxxxxAB or 0xC2000 to 0xC3FFF)

Is expected that the ROM wil be reallocatable, and should work on any of the 16 bank of ROM (PENDING TO CONFIRM) so the 6821 can be also allocated in any of this bank.

The QSound manual indicate that 2 system variables are defined to indentify the real position in the bank, SV.AYBAS (0x28160) and SV.AYJMP (0x28164) but some toolkits are also using this address for his internal propouse.

A definitive way to identify the real base address of the interface is not clear, searching for "QSound" ascii signature at beggining of the rom block is another options but has also it's cabeats.

## PIO (MC6821)
The pio has 2 8-bit lines, that the use of A or B is defined by RS1, that is A1 in the Sinclair QL. the Port A is linked to the data of the PSG, and the port B is using bit 0 and bit 2 to manage the selection of the PSG, bit 3 ant bit 4 are exposed in the 2x13 pin conector to be used as strobe and busy in the centronics printer port part of the interface.

- RS0 on 6821 is conected to The A0 on the QL
- RS1 on 6821 is conected to The A1 on the QL
- RESET on 6821 is conected to RESET on the QL

RS0 manage the Port in use, 0 for A, 1 for B. 

- When RS1 is 1, you write to Control register of each port.
- When RS1 is 0, depend on the bit 2 of Control register you access to Data Direction (if 0) or the port itself (if 1)

The other bits of Control Register are related to interuptions and are not in use for this card.

When you write to the Data direction, each bit indicate if Port bit is Input (when 1) or output (when 0)

Control Register Port A is 0b1100001xxxxxxxxxxx00 or 0xC2000 
General Register Port A is 0b1100001xxxxxxxxxxx10 or 0xC2002
Control Register Port B is 0b1100001xxxxxxxxxxx01 or 0xC2001
General Register Port B is 0b1100001xxxxxxxxxxx11 or 0xC2003

## PSG (GI AY-3-8910)

The three channels are interconected, so sound is monoaural.

- The data bus of the PGS is conected to the Port A of the PIO.
- BC1 is conected to bit 0 of PIO's port B 
- BC2 is tied to 1 (Vcc) 
- BDIR is conected to bit 2 of PIO's port B 
- CLOCK is conected to E of QL, so it's 750Khz, as it's 1/10 of clock of CPU 68008
- RESET on PSG is conected to RESET on the QL

So a sequence to write to a register on the PSG shall be:

```
; INIT OF PIO
; at 0xC0032
LEA       LPSG_io,A5          ; A5 = base address of I/O Port of 6821, (0xC2000) 
; Really  LEA $1FCC(PC),A5 it use relative directions (d16,PC) so (0xC0032 + 0x02 + 0x1FFCC = 0xC2000)

CLR.B     $0001(A5)           ; disable all interupts and select Direction for Port A
MOVE.B    #$FF,$0000(A5)      ; configure all bits of Port A as Output
MOVE.B    #$04,$0001(A5)      ; select register data, any write to $0000(A5) now will be put on Port A

CLR.B     $0003(A5)           ; disable all interupts and select Direction for Port B
MOVE.B    #$0F,$0002(A5)      ; set BC0, BDIR, Strobe as ouput, and Busy as input
MOVE.B    #$04,$0003(A5)      ; select register data, any access to $0002(A5) now will be to Port B

MOVE.B    #$0A,$0002(A5)      ; Set BC1 to 0, and BDIR to 0, so PSG inactive (bit 1 and bit 4(Strobe) as 1 but not used) 

; Write D1 on register D2

MOVE.B    D2  ,$0000(A5)      ; Write the Register Number to port A
MOVE.B    #$0F,$0002(A5)      ; Set BC1 to 1, and BDIR to 1 latch adress of port A to PSG
MOVE.B    #$0A,$0002(A5)      ; Set BC1 to 0, and BDIR to 0, so PSG inactive

MOVE.B    D1,  $0000(A5)      ; Write the Data to port A
MOVE.B    #$0E,$0002(A5)      ; Set BC1 to 0, and BDIR to 1 write data of port A to register of PSG
MOVE.B    #$0A,$0002(A5)      ; Set BC1 to 0, and BDIR to 0, so PSG inactive
```

```
; Read on D1 the register D2 (not tested)

MOVE.B    D2  ,$0000(A5)      ; Write the Register Number to port A
MOVE.B    #$0F,$0002(A5)      ; Set BC1 to 1, and BDIR to 1 latch adress of port A to PSG
MOVE.B    #$0A,$0002(A5)      ; Set BC1 to 0, and BDIR to 0, so PSG inactive

CLR.B     $0001(A5)           ; disable all interupts and select Direction for Port A
MOVE.B    #$00,$0000(A5)      ; configure all bits of Port A as Input
MOVE.B    #$04,$0001(A5)      ; select register data, any read on $0000(A5) now will be from Port A

MOVE.B    #$08,$0002(A5)      ; Set BC1 to 1, and BDIR to 0 read register of PSG and put in port A
MOVE.B    $0000(A5),D1        ; Read port A and put on D1
MOVE.B    #$0A,$0002(A5)      ; Set BC1 to 0, and BDIR to 0, so PSG inactive

CLR.B     $0001(A5)           ; disable all interupts and select Direction for Port A
MOVE.B    #$FF,$0000(A5)      ; configure all bits of Port A as Output
MOVE.B    #$04,$0001(A5)      ; select register data, any write to $0000(A5) now will be put on Port A
```

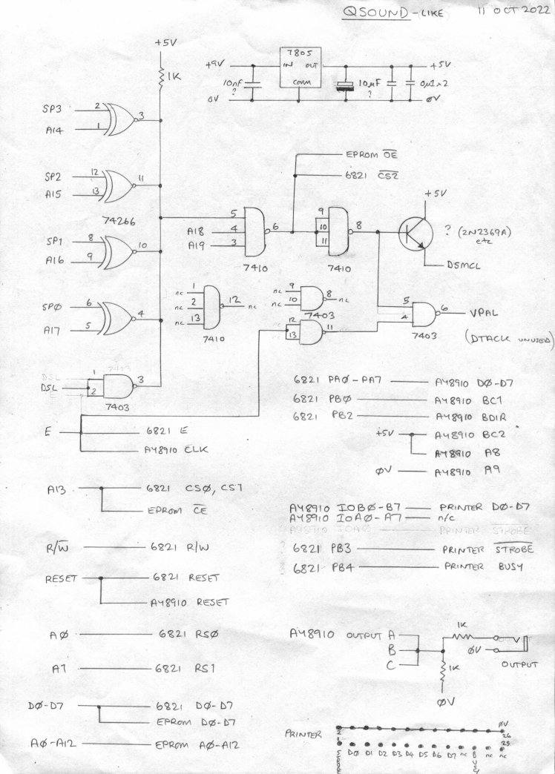
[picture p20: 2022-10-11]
INFO/QSsch2.jpg

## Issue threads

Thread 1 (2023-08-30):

Errors in schema and on board silkscreen

jurajlutter, 2023-08-30:
There are some issues in schematics and in gerber:

- Schematics and gerber mentions 27512 EPROM while the correct one (as in BOM) is 2764
- Schematic has DIN connector upside down. Meaning: pin 1 should be 32, etc. A and B sides are OK.

jurajlutter, 2023-11-11:
Another problem on PCB (found while I've been wondering why the left channel is silent): The signal leads to pins 2 and 4 on the jack J3. Instead, it should be routed to pin 2 and 5 (with pin "1" being GND).

alvaroalea, 2023-11-20:
I put a note in the schematic about the 27512, and fix the pins of the Jack, still pending the DIN connector, I need to clear my symbol library first.

alvaroalea, 2023-12-26:
I think I correct everything now, so I close the issue, feel free to open again if additional errors appear.

Closed 2023-12-26.

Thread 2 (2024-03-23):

7805 position conflict

plasticuser, 2024-03-23:
The 7805 is too close to the card edge, preventing easy insertion of the board causing misalignment. This could increase risk of bent pins in the expansion bus connector. It also causes particular problems in metalised US QL cases - causing the entire shell EMI layer to be at +5V.

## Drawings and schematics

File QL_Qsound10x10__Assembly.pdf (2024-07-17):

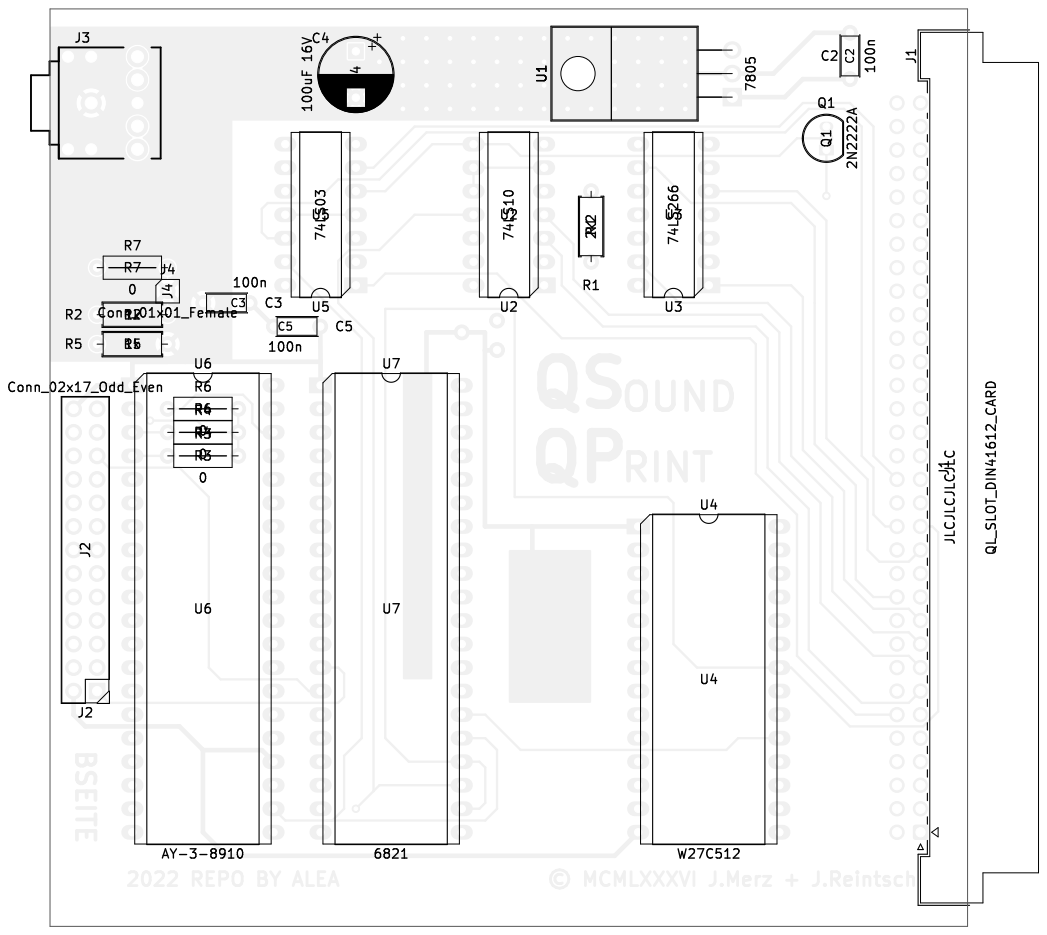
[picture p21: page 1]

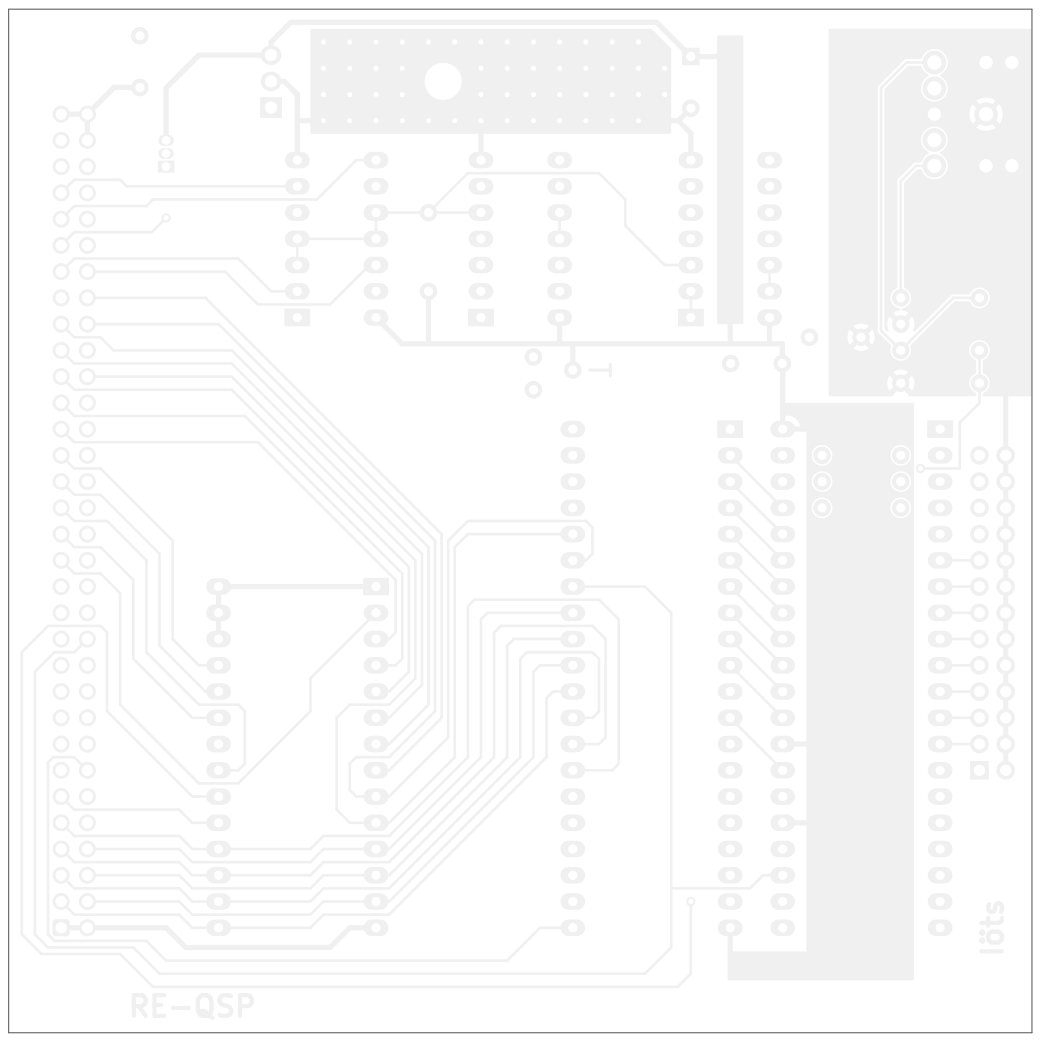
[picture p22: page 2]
Iöts; RE-QSP; D Date: 2023-12-26 KiCad; E.D.A. 8.0.3 Size: A4; Rev: 0.1b; Id: 1/1 Title: QSound/Qprint; Interface for Sinclair QL; File: QL_Qsound10x10.kicad_pcb Sheet: Alvaro Alea; Fdz

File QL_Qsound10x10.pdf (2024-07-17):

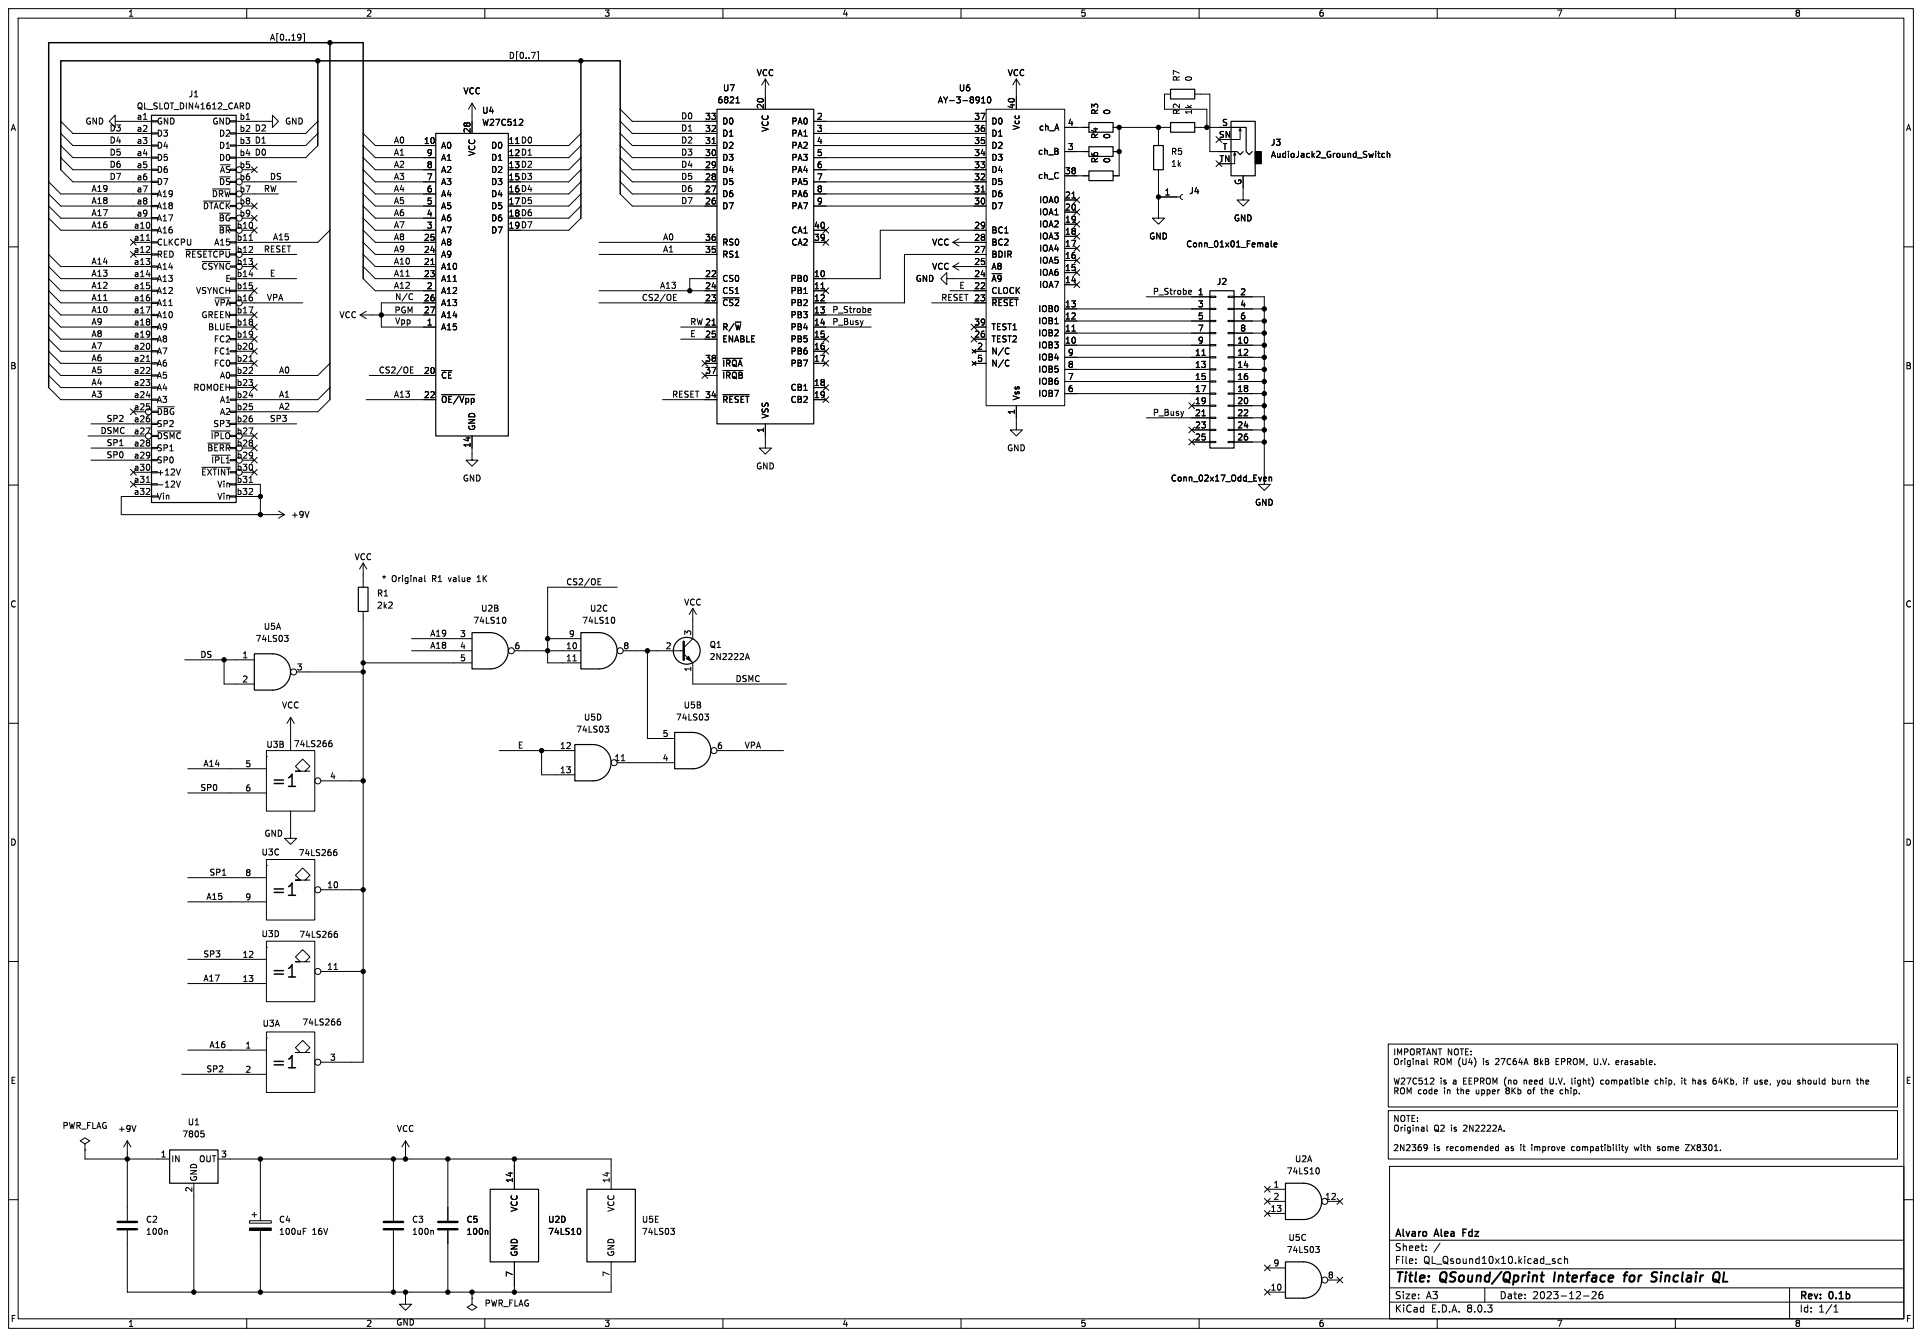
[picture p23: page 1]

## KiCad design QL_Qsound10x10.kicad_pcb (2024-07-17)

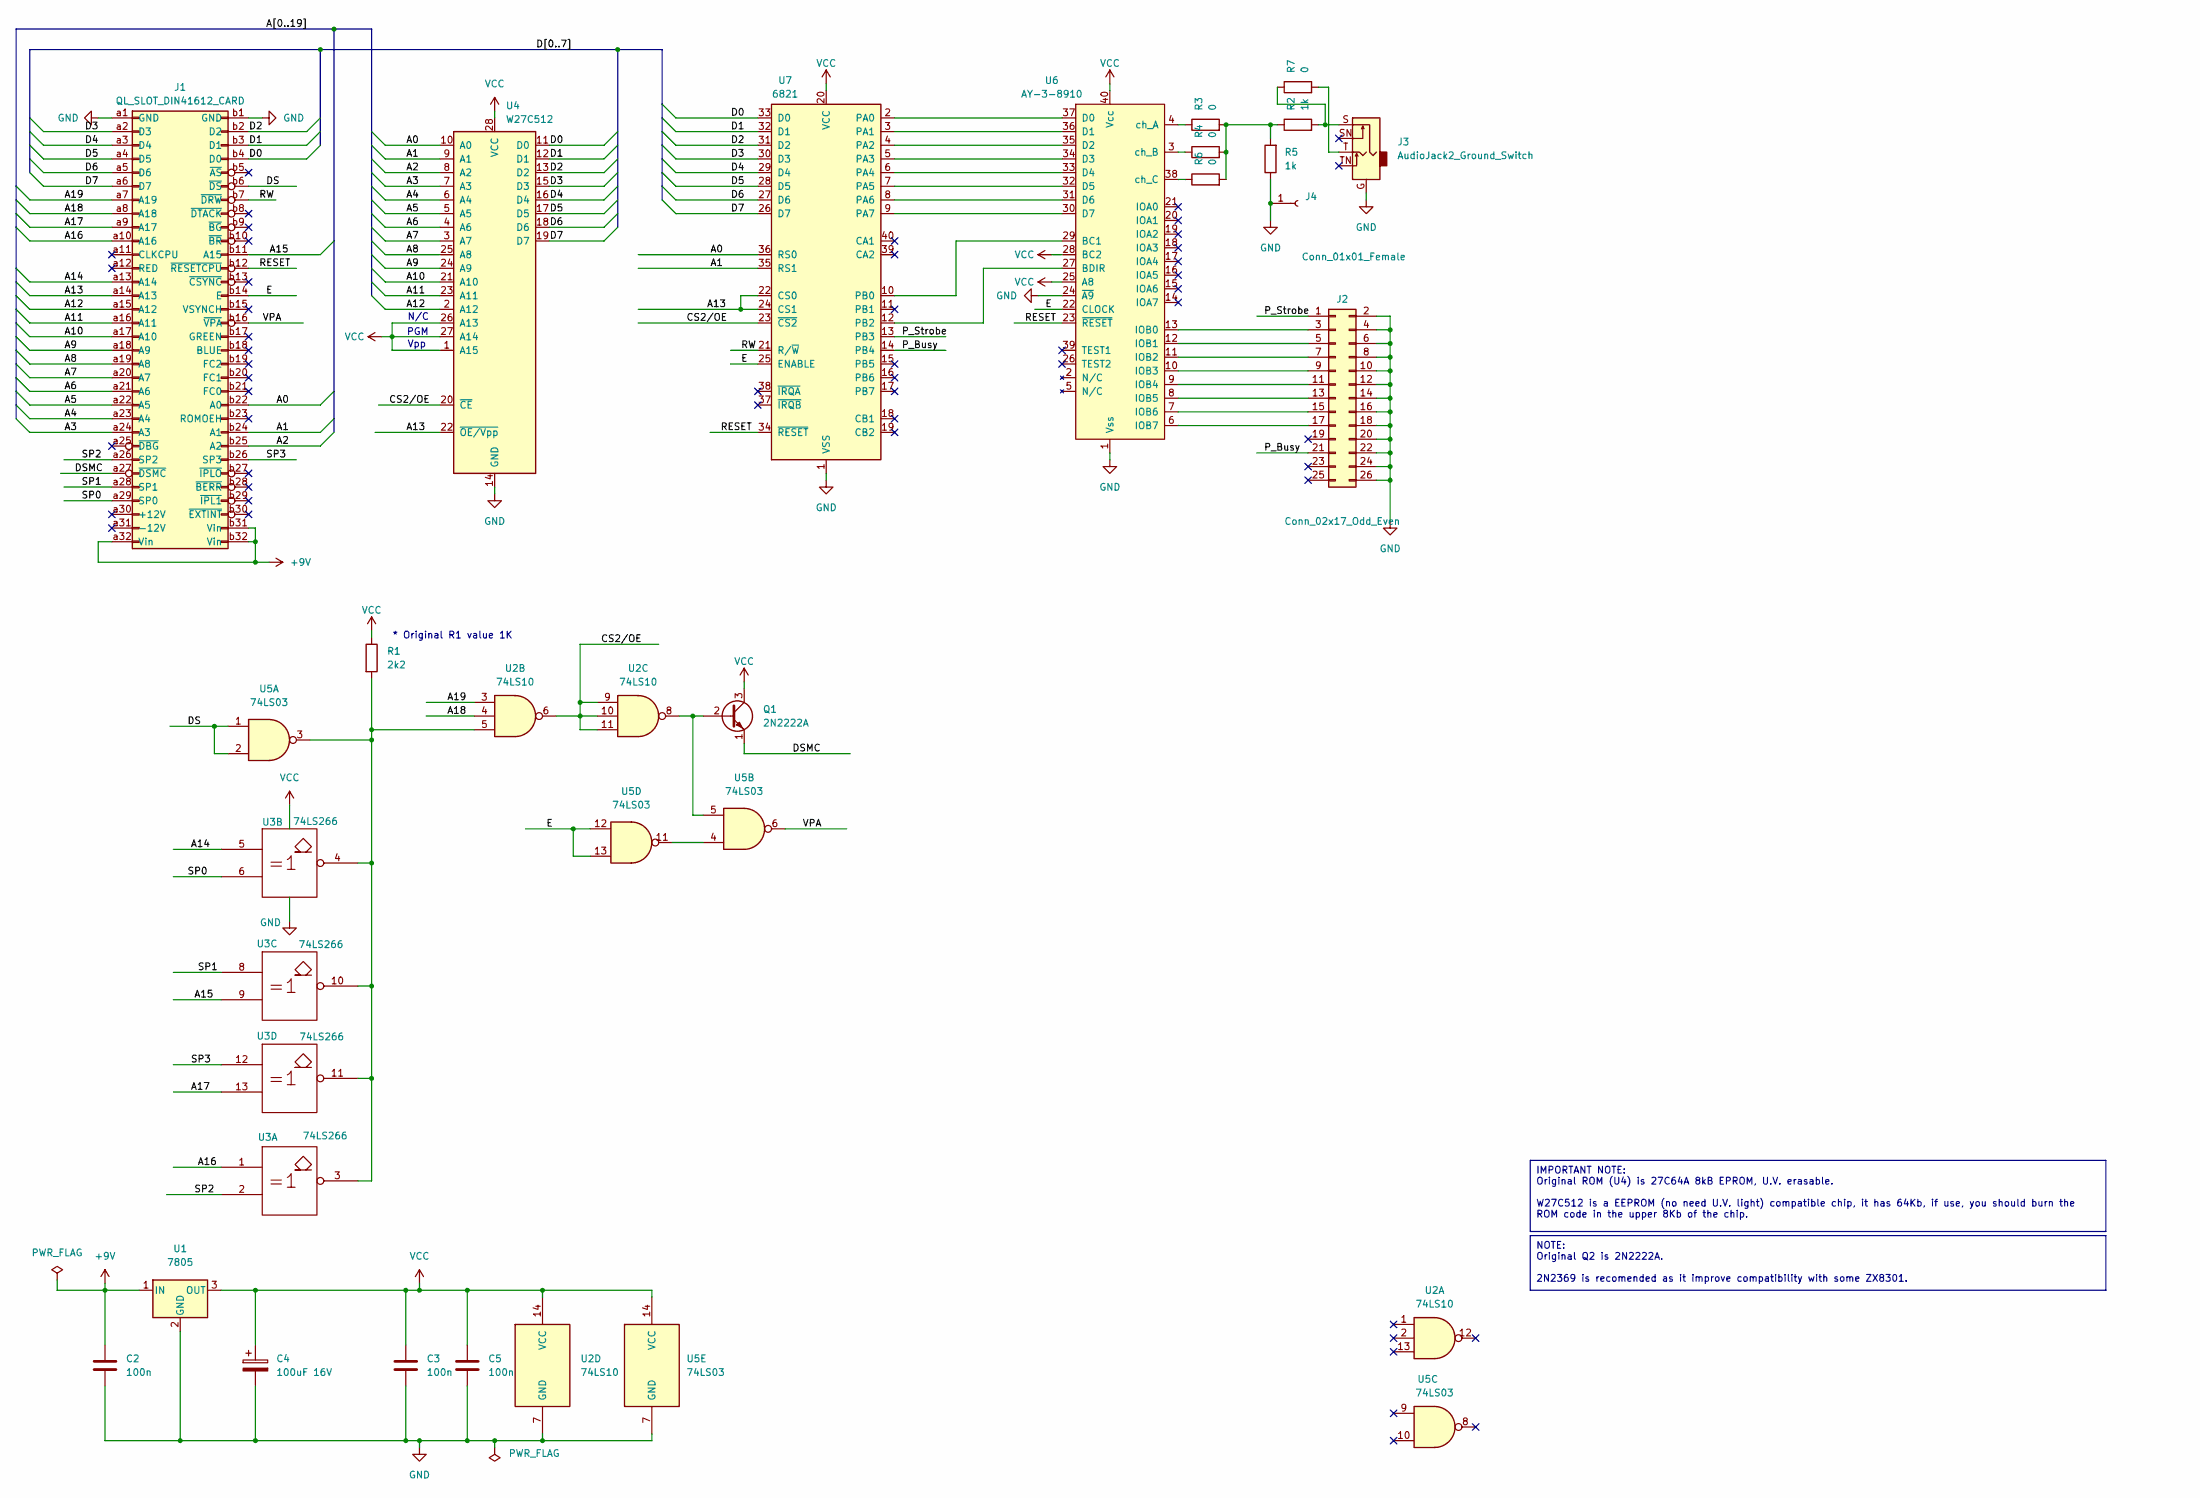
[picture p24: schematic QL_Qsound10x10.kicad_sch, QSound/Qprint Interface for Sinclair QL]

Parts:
C2, C3, C5: 100n; C_Disc_D4.3mm_W1.9mm_P5.00mm
C4: 100uF 16V; CP_Radial_D8.0mm_P5.00mm
J1: QL_SLOT_DIN41612_CARD; DIN41612_B_2x32_Female_Horizontal_THT
J2: Conn_02x17_Odd_Even; PinHeader_2x13_P2.54mm_Vertical
J3: AudioJack2_Ground_Switch
J4: Conn_01x01_Female; PinHeader_1x01_P2.54mm_Vertical
Q1: 2N2222A; TO-92_Inline
R1: 2k2; R_Axial_DIN0207_L6.3mm_D2.5mm_P7.62mm_Horizontal
R2, R5: 1k; R_Axial_DIN0207_L6.3mm_D2.5mm_P7.62mm_Horizontal
R3, R4, R6, R7: 0; R_Axial_DIN0207_L6.3mm_D2.5mm_P7.62mm_Horizontal
U1: 7805; TO-220-3_Horizontal_TabDown
U2: 74LS10; DIP-14_W7.62mm_LongPads
U3: 74LS266; DIP-14_W7.62mm_LongPads
U4: W27C512; DIP-28_W15.24mm_LongPads
U5: 74LS03; DIP-14_W7.62mm_LongPads
U6: AY-3-8910; DIP-40_W15.24mm_LongPads
U7: 6821; DIP-40_W15.24mm_LongPads

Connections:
+9V: C2.1, J1.a32 (Vin), J1.b31 (Vin), J1.b32 (Vin), U1.1 (IN)
/A0: J1.b22 (A0), U4.10 (A0), U7.36 (RS0)
/A1: J1.b24 (A1), U4.9 (A1), U7.35 (RS1)
/A2: J1.b25 (A2), U4.8 (A2)
/A3: J1.a24 (A3), U4.7 (A3)
/A4: J1.a23 (A4), U4.6 (A4)
/A5: J1.a22 (A5), U4.5 (A5)
/A6: J1.a21 (A6), U4.4 (A6)
/A7: J1.a20 (A7), U4.3 (A7)
/A8: J1.a19 (A8), U4.25 (A8)
/A9: J1.a18 (A9), U4.24 (A9)
/A10: J1.a17 (A10), U4.21 (A10)
/A11: J1.a16 (A11), U4.23 (A11)
/A12: J1.a15 (A12), U4.2 (A12)
/A13: J1.a14 (A13), U4.22 (~OE/Vpp), U7.22 (CS0), U7.24 (CS1)
/A14: J1.a13 (A14), U3.5
/A15: J1.b11 (A15), U3.9
/A16: J1.a10 (A16), U3.1
/A17: J1.a9 (A17), U3.13
/A18: J1.a8 (A18), U2.4
/A19: J1.a7 (A19), U2.3
/CS2/OE: U2.6, U2.9, U2.10, U2.11, U4.20 (~CE), U7.23 (~CS2)
/D0: J1.b4 (D0), U4.11 (D0), U7.33 (D0)
/D1: J1.b3 (D1), U4.12 (D1), U7.32 (D1)
/D2: J1.b2 (D2), U4.13 (D2), U7.31 (D2)
/D3: J1.a2 (D3), U4.15 (D3), U7.30 (D3)
/D4: J1.a3 (D4), U4.16 (D4), U7.29 (D4)
/D5: J1.a4 (D5), U4.17 (D5), U7.28 (D5)
/D6: J1.a5 (D6), U4.18 (D6), U7.27 (D6)
/D7: J1.a6 (D7), U4.19 (D7), U7.26 (D7)
/DS: J1.b6 (~DS), U5.1, U5.2
/DSMC: J1.a27 (~DSMC), Q1.1 (E)
/E: J1.b14 (E), U5.12, U5.13, U6.22 (CLOCK), U7.25 (ENABLE)
/P_Busy: J2.21, U7.14 (PB4)
/P_Strobe: J2.1, U7.13 (PB3)
/RESET: J1.b12 (~RESETCPU), U6.23 (~RESET), U7.34 (~RESET)
/RW: J1.b7 (~DRW), U7.21 (R/~W)
/SP0: J1.a29 (SP0), U3.6
/SP1: J1.a28 (SP1), U3.8
/SP2: J1.a26 (SP2), U3.2
/SP3: J1.b26 (SP3), U3.12
/VPA: J1.b16 (~VPA), U5.6
GND: C2.2, C3.2, C4.2, C5.2, J1.a1 (GND), J1.b1 (GND), J2.2, J2.4, J2.6, J2.8, J2.10, J2.12, J2.14, J2.16, J2.18, J2.20, J2.22, J2.24, J2.26, J3.G, J4.1, R5.1, U1.2 (GND), U2.7 (GND), U3.7 (GND), U4.14 (GND), U5.7 (GND), U6.1 (Vss), U6.24 (~A9), U7.1 (VSS)
unnamed: J2.3, U6.13 (IOB0)
unnamed: J2.5, U6.12 (IOB1)
unnamed: J2.7, U6.11 (IOB2)
unnamed: J2.9, U6.10 (IOB3)
unnamed: J2.11, U6.9 (IOB4)
unnamed: J2.13, U6.8 (IOB5)
unnamed: J2.15, U6.7 (IOB6)
unnamed: J2.17, U6.6 (IOB7)
unnamed: J3.S, R2.2, R7.1
unnamed: J3.T, R7.2
unnamed: Q1.2 (B), U2.8, U5.5
unnamed: R1.2, U2.5, U3.3, U3.4, U3.10, U3.11, U5.3
unnamed: R2.1, R3.2, R4.2, R5.2, R6.2
unnamed: U5.4, U5.11
unnamed: U6.29 (BC1), U7.10 (PB0)
unnamed: U6.27 (BDIR), U7.12 (PB2)
unnamed: U6.37 (D0), U7.2 (PA0)
unnamed: U6.36 (D1), U7.3 (PA1)
unnamed: U6.35 (D2), U7.4 (PA2)
unnamed: U6.34 (D3), U7.5 (PA3)
unnamed: U6.33 (D4), U7.6 (PA4)
unnamed: U6.32 (D5), U7.7 (PA5)
unnamed: U6.31 (D6), U7.8 (PA6)
unnamed: U6.30 (D7), U7.9 (PA7)
unnamed: R3.1, U6.4 (ch_A)
unnamed: R4.1, U6.3 (ch_B)
unnamed: R6.1, U6.38 (ch_C)
VCC: C3.1, C4.1, C5.1, Q1.3 (C), R1.1, U1.3 (OUT), U2.14 (VCC), U3.14 (VCC), U4.1 (A15), U4.26 (A13), U4.27 (A14), U4.28 (VCC), U5.14 (VCC), U6.25 (A8), U6.28 (BC2), U6.40 (Vcc), U7.20 (VCC)

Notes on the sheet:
NOTE: Original Q2 is 2N2222A. 2N2369 is recomended as it improve compatibility with some ZX8301.
IMPORTANT NOTE: Original ROM (U4) is 27C64A 8kB EPROM, U.V. erasable. W27C512 is a EEPROM (no need U.V. light) compatible chip, it has 64Kb, if use, you should burn the ROM code in the upper 8Kb of the chip.
Vpp
N/C
* Original R1 value 1K
PGM

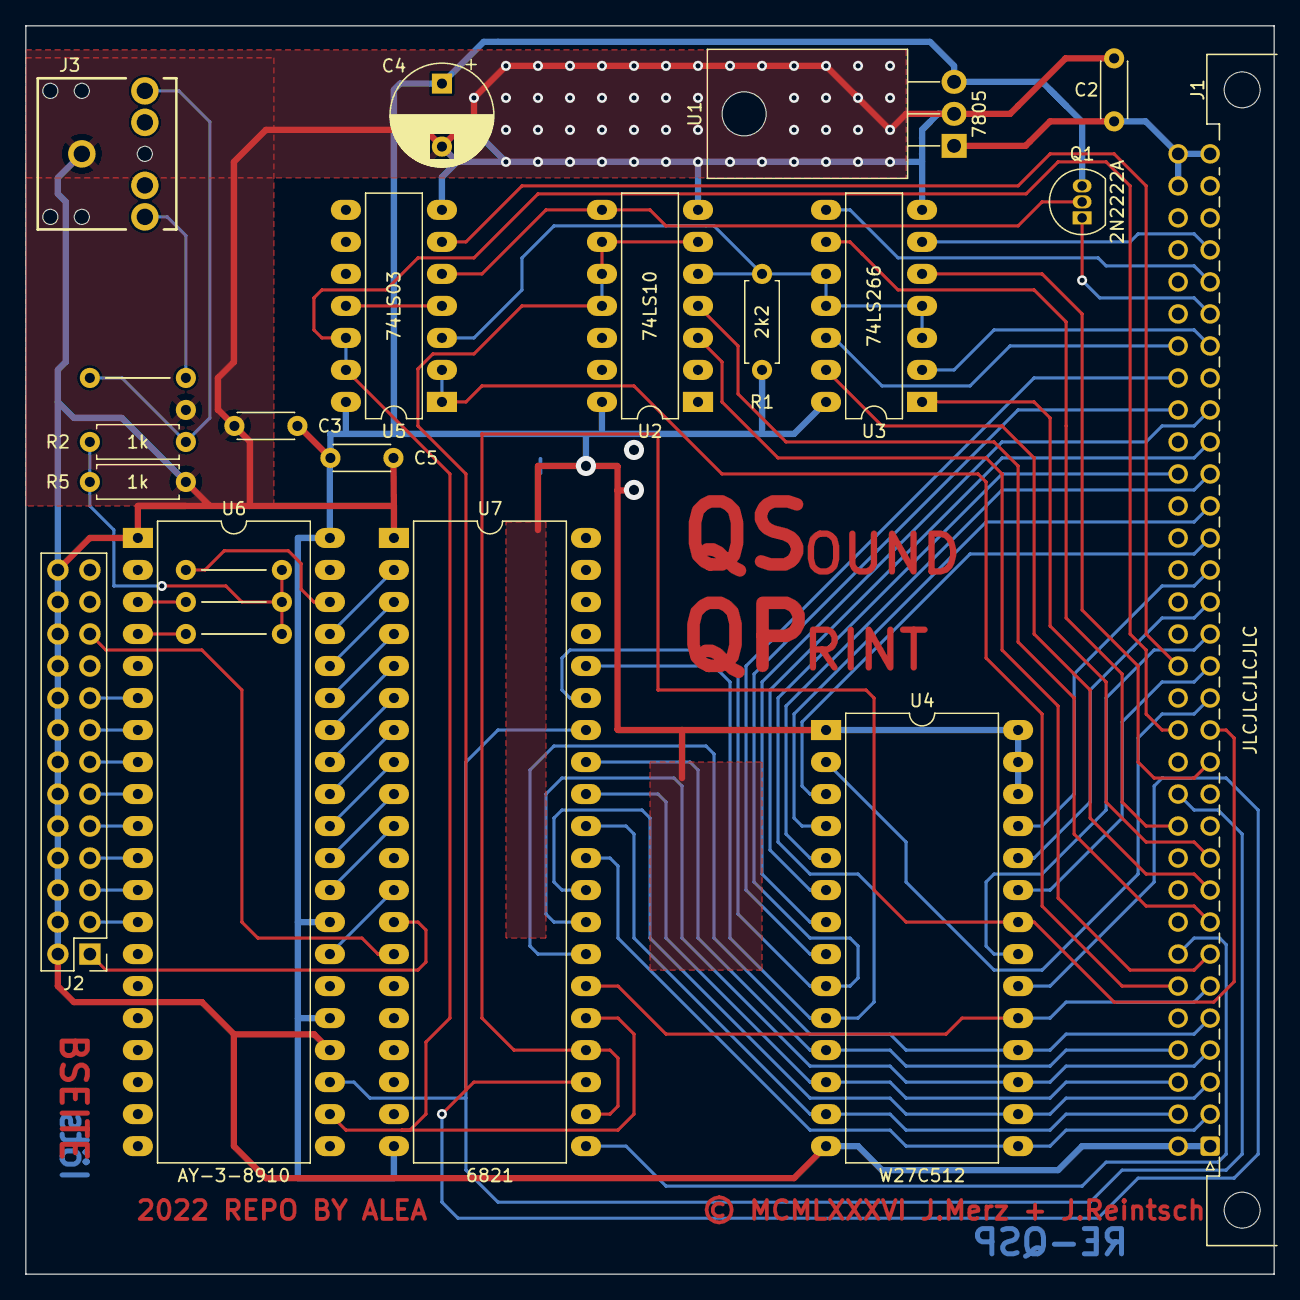
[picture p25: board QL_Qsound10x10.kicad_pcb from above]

Board: 2 copper layers, 99.1 x 99.1 mm, 23 parts (0 on the bottom side), 71 nets.

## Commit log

2022-09-26 update info
    [QL_Qsound10x10.kicad_pcb, QL_Qsound10x10.kicad_sch]
2022-10-04 complete strings in pcb
    [QL_Qsound10x10-B_Cu.gbr, QL_Qsound10x10-B_Mask.gbr, QL_Qsound10x10-B_Paste.gbr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]
2022-10-04 Noticia Importante, PCB mal
2022-10-11 Update, now work all
    [QL_Qsound10x10-B_Cu.gbr, QL_Qsound10x10-B_Mask.gbr, QL_Qsound10x10-B_Paste.gbr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]
2022-10-12 tracks more similar to original
    [QL_Qsound10x10-B_Cu.gbr, QL_Qsound10x10-B_Mask.gbr, QL_Qsound10x10-B_Paste.gbr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]
2023-11-19 Update some errors in PCB
    [QL_Qsound10x10-B_Cu.gbr, QL_Qsound10x10-B_Mask.gbr, QL_Qsound10x10-B_Paste.gbr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]
2023-12-26 Updated pins on QL conector
    [QL_Qsound10x10-B_Cu.gbr, QL_Qsound10x10-B_Mask.gbr, QL_Qsound10x10-B_Paste.gbr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]
2024-07-17 move 7805 down
    [QL_Qsound10x10-B_Cu.gbr, QL_Qsound10x10-B_Mask.gbr, QL_Qsound10x10-B_Paste.gbr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]

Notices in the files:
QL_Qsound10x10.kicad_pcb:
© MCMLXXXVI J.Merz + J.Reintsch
